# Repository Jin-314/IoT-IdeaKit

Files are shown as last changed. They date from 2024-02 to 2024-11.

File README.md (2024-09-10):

# Turtle Pico - Making electronics work easier and more widely

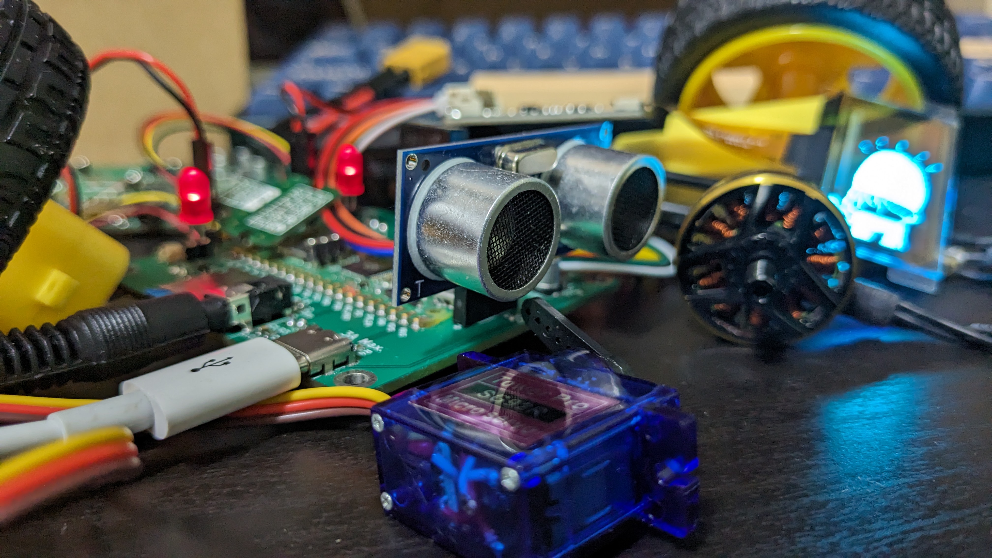
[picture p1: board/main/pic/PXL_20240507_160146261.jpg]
Turtle Pico


The Turtle Pico Board which looks like a turtle, uses connectors on the board for easy connection to components. The board is equipped with Raspberry Pi Pico W, and programming is easy with Micropython.

When you want to build something, just buy the components and plug them into this board! That's all there is to wiring. Then all you have to do is write the programming.

Don't know how to program? Don't worry. You can find some programming examples in the official repository.

## Specific & Environment build

Please see the specifications for a summary of each use.

The specifications are available in Japanese and English, so you can check them in the language of your choice.

[English](board/main/specific/specific_en.pdf)

[Japanese](board/main/specific/specific_jp.pdf)

## Case

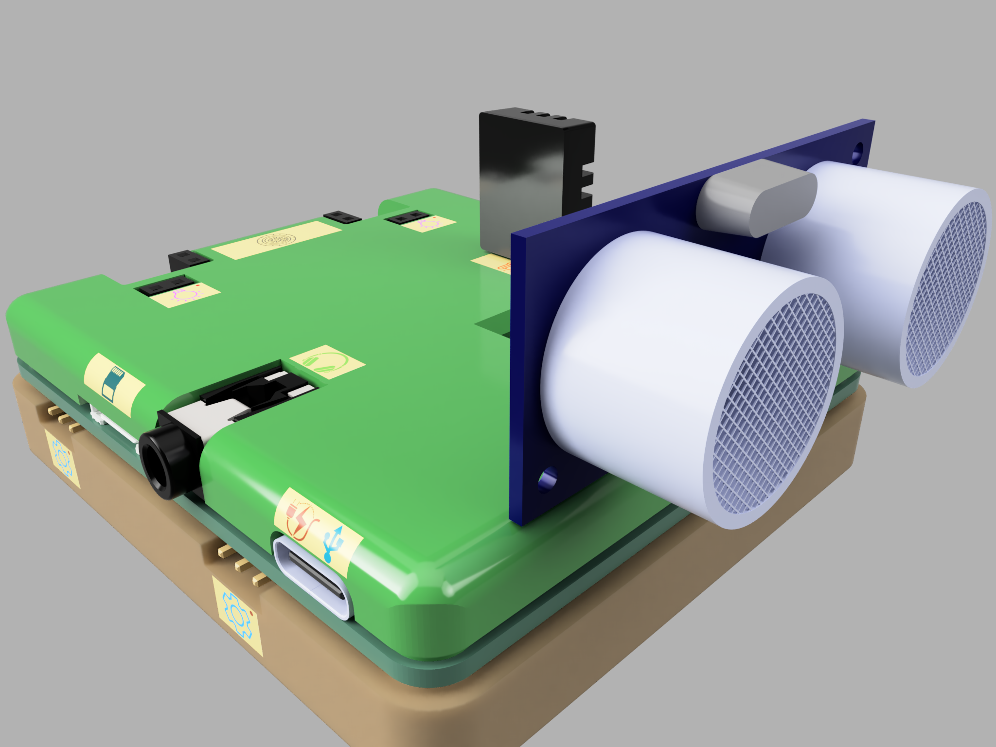
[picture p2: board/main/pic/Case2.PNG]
case


Turtle Pico Package is available in [**board/main/Case**](https://github.com/Jin-Neuron/Turtle-Pico/tree/master/board/main/Case).

## Purchase your board



Turtle Pico boards can currently only be purchased from [PCBWay's Shared Project Page](https://www.pcbway.com/project/shareproject/Turtle_Pico_Board_c183b11f.html). Once officially released, we plan to make it available for purchase at various online stores. 

## License

This repository includes multiple components with different licenses.

Please reffer to [LICENSE File](License.txt).

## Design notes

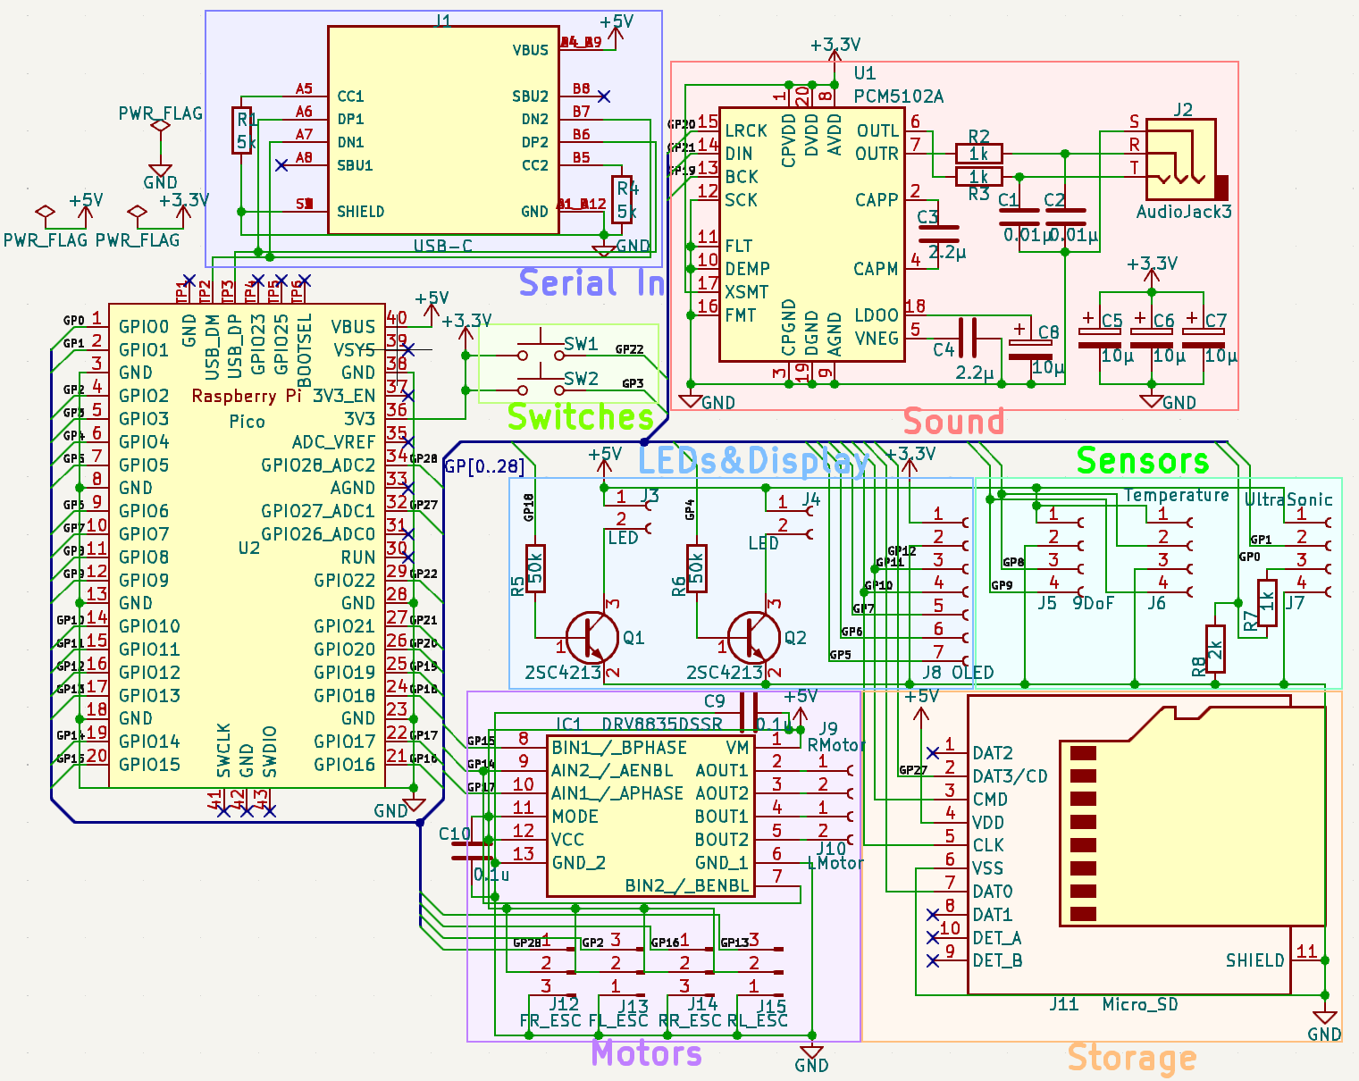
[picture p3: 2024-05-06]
board/main/pic/v.1/schematics.png

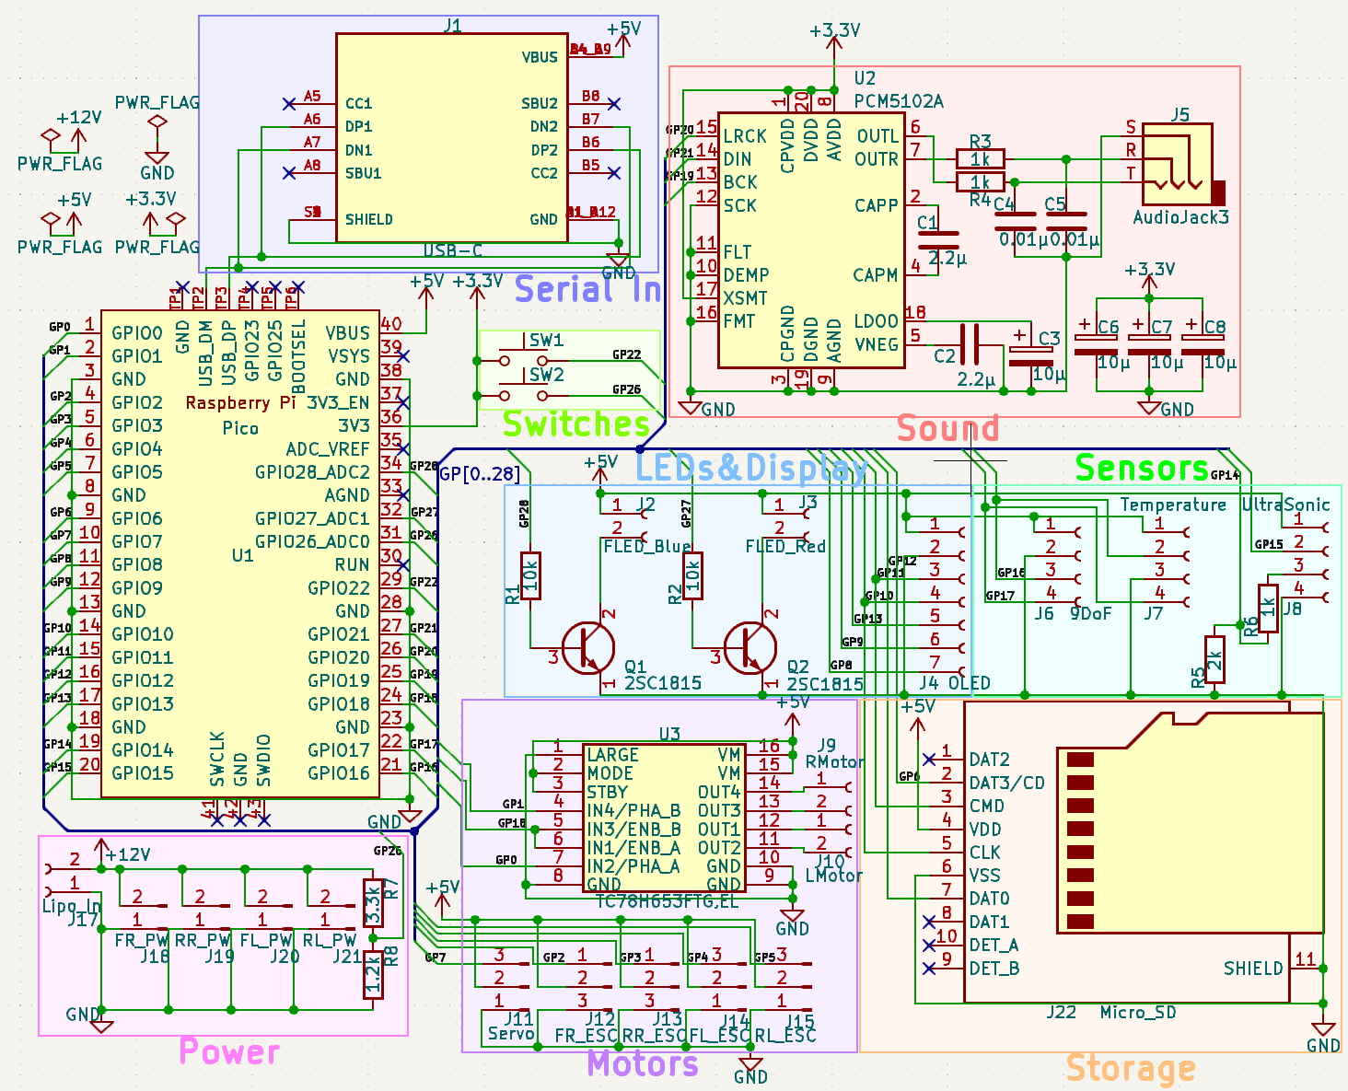
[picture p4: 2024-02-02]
board/trial/pic/Schematics.png

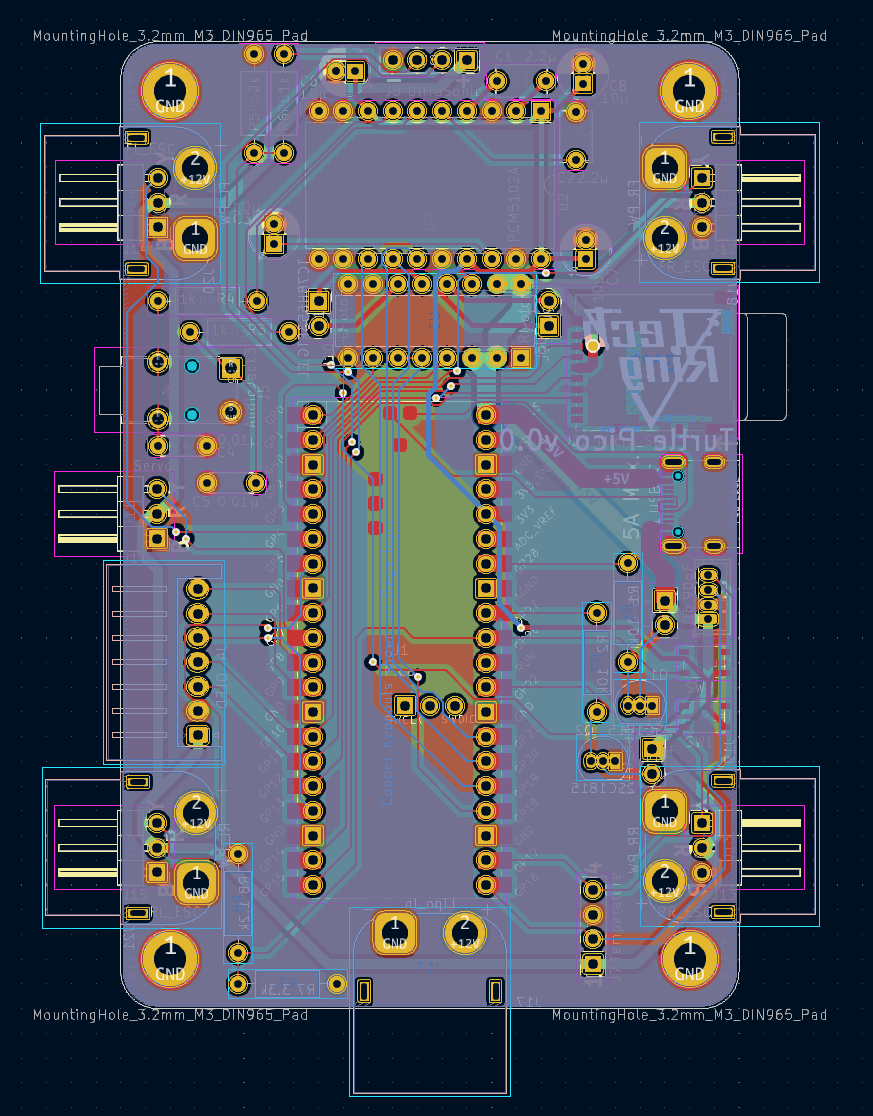
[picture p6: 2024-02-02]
board/trial/pic/PCB_4.png

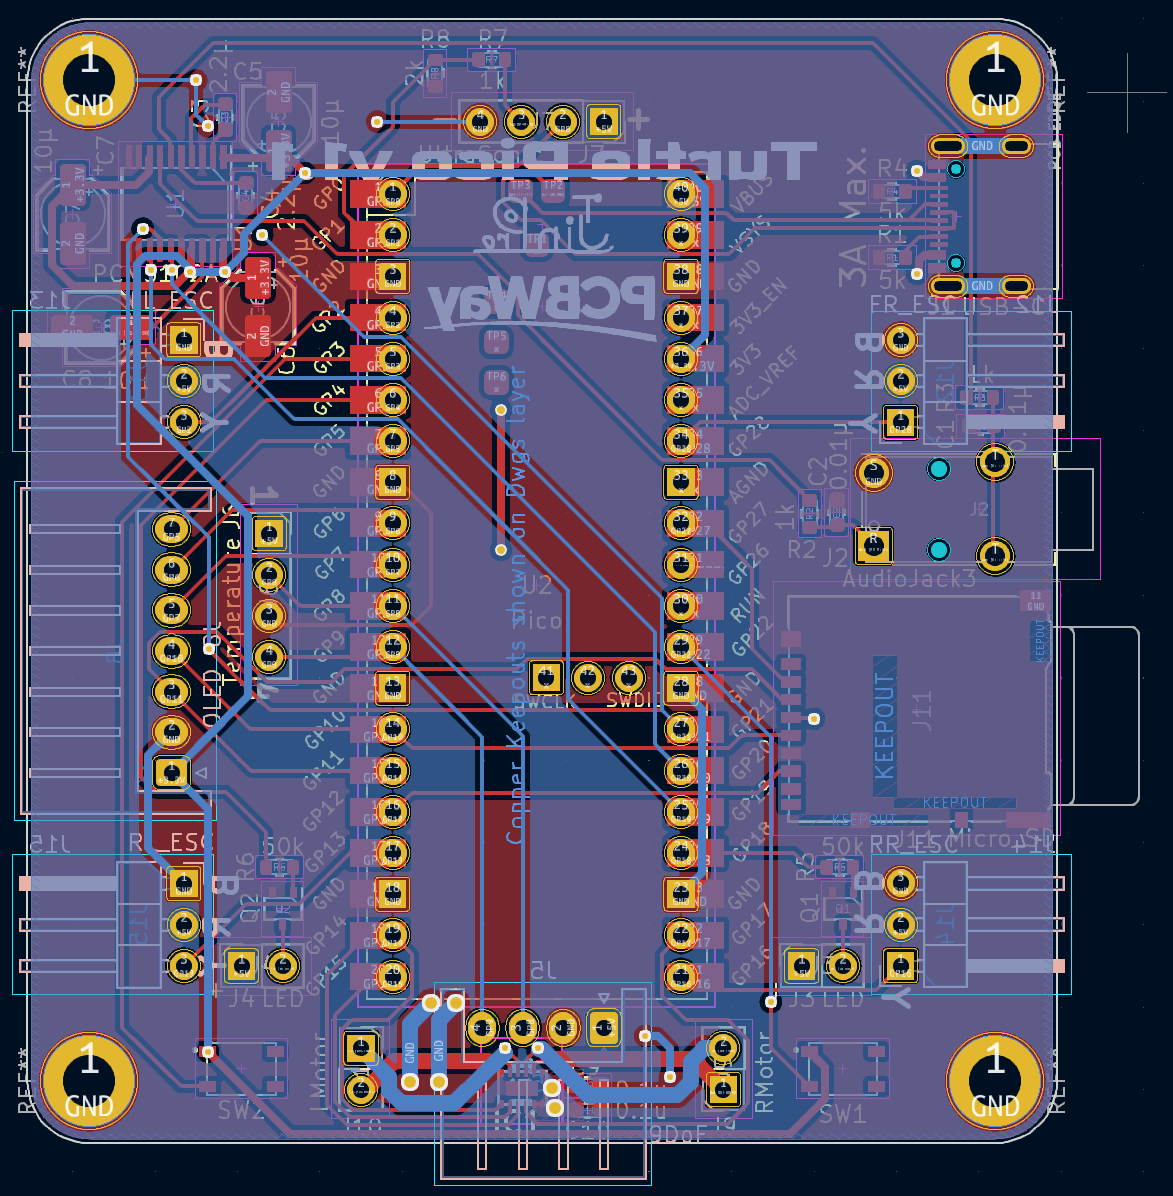
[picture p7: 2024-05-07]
board/main/pic/v.1/PCB_2.png

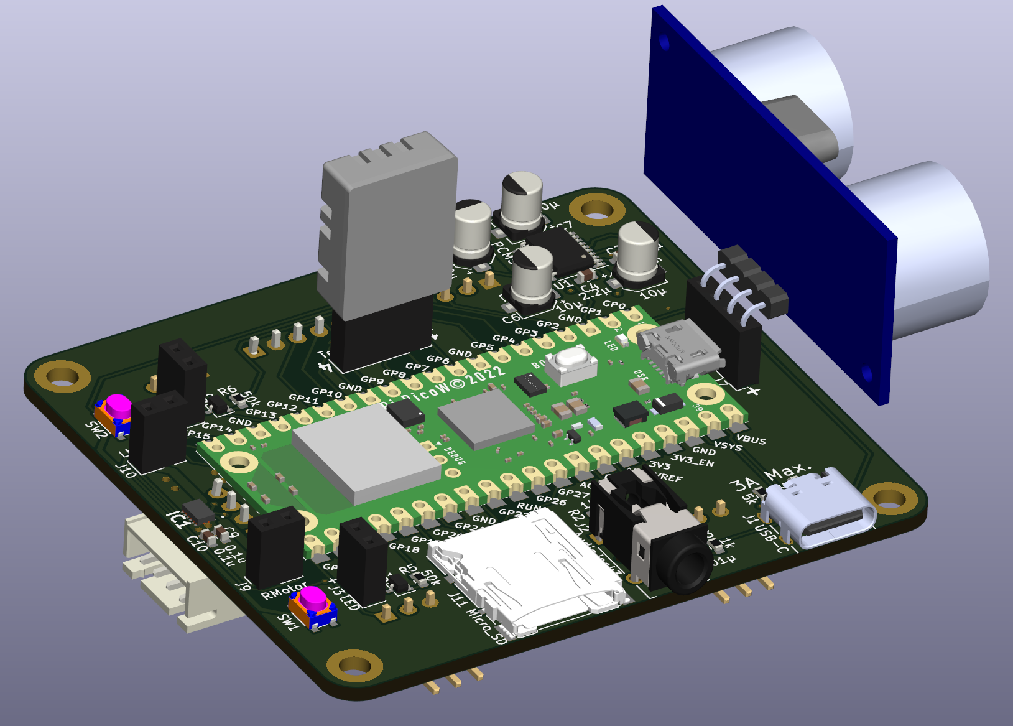
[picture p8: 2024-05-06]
board/main/pic/v.1/3D.png

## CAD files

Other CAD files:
board/main/Case/UpperCase.step
board/main/TurtlePico.step
board/trial/TurtlePico.step
board/main/Case/LowerCase.step

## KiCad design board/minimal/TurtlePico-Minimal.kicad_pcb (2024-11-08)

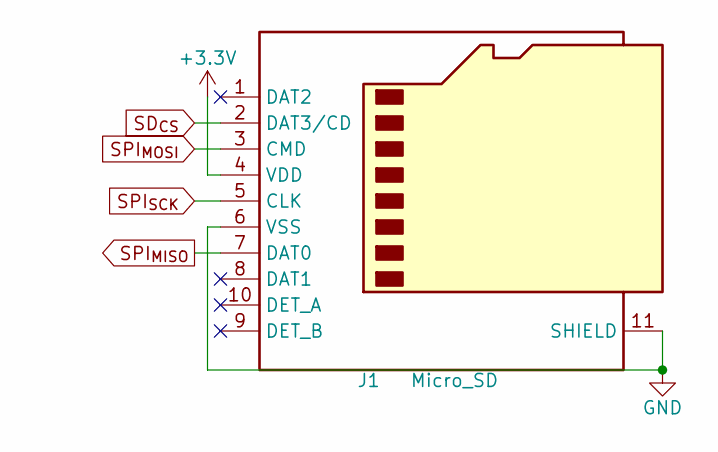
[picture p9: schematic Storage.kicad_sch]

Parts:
J1: Micro_SD; microSD_HC_Hirose_DM3D-SF; Manufacturer_Part_Number DM3AT-SF-PEJM5; Mouser Part Number 798-DM3AT-SF-PEJM5

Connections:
+3.3V: J1.4 (VDD); also elsewhere on the board
GND: J1.6 (VSS), J1.11 (SHIELD); also elsewhere on the board
SD_{CS}: J1.2 (DAT3/CD); also elsewhere on the board
SPI_{MISO}: J1.7 (DAT0); also elsewhere on the board
SPI_{MOSI}: J1.3 (CMD); also elsewhere on the board
SPI_{SCK}: J1.5 (CLK); also elsewhere on the board

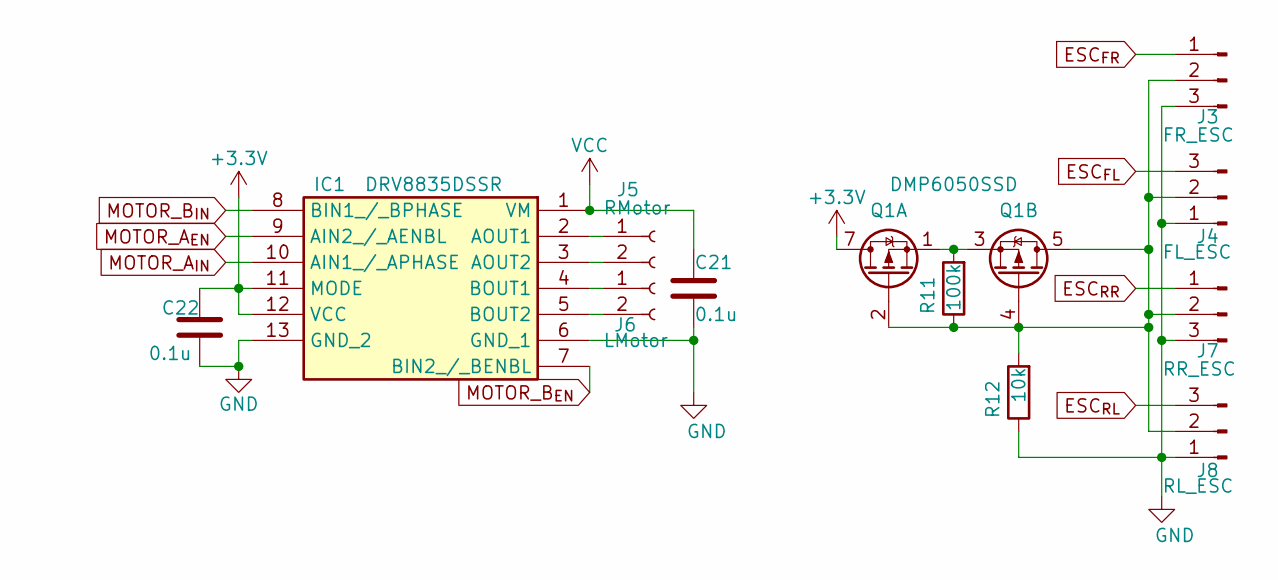
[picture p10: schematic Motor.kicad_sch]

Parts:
C21, C22: 0.1u; C_0201_0603Metric; Manufacturer_Part_Number GCM188R71C104KA37J; Mouser Part Number 81-GCM188R71C104KA7J
IC1: DRV8835DSSR; WSON-12-1EP_3x2mm_P0.5mm_EP1x2.65_ThermalVias; Mouser Part Number 595-DRV8835DSSR
J3: FR_ESC; PinHeader_1x03_P2.54mm_Horizontal
J4: FL_ESC; PinHeader_1x03_P2.54mm_Horizontal
J5: RMotor; PinSocket_1x02_P2.54mm_Vertical
J6: LMotor; PinSocket_1x02_P2.54mm_Vertical
J7: RR_ESC; PinHeader_1x03_P2.54mm_Horizontal
J8: RL_ESC; PinHeader_1x03_P2.54mm_Horizontal
Q1: DMP6050SSD; SOIC-8_3.9x4.9mm_P1.27mm
R11: 100k; R_0603_1608Metric; Manufacturer_Part_Number RN73H1JTTD5102F100; Mouser Part Number 660-RN73H1JT5102F100
R12: 10k; R_0603_1608Metric; Manufacturer_Part_Number RN73H1JTTD5102F100; Mouser Part Number 660-RN73H1JT5102F100

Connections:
+3.3V: C22.1, IC1.11 (MODE), IC1.12 (VCC), Q1.7 (D1), Q1.8 (D1); also elsewhere on the board
ESC_{FL}: J4.3; also elsewhere on the board
ESC_{FR}: J3.1; also elsewhere on the board
ESC_{RL}: J8.3; also elsewhere on the board
ESC_{RR}: J7.1; also elsewhere on the board
GND: C21.2, C22.2, IC1.6 (GND_1), IC1.13 (GND_2), J3.3, J4.1, J7.3, J8.1, R12.1; also elsewhere on the board
MOTOR_A_{EN}: IC1.9 (AIN2_/_AENBL); also elsewhere on the board
MOTOR_A_{IN}: IC1.10 (AIN1_/_APHASE); also elsewhere on the board
MOTOR_B_{EN}: IC1.7 (BIN2_/_BENBL); also elsewhere on the board
MOTOR_B_{IN}: IC1.8 (BIN1_/_BPHASE); also elsewhere on the board
unnamed: IC1.2 (AOUT1), J5.1
unnamed: IC1.3 (AOUT2), J5.2
unnamed: IC1.4 (BOUT1), J6.1
unnamed: IC1.5 (BOUT2), J6.2
unnamed: J3.2, J4.2, J7.2, J8.2, Q1.2 (G1), Q1.4 (G2), Q1.5 (D2), Q1.6 (D2), R11.1, R12.2
unnamed: Q1.1 (S1), Q1.3 (S2), R11.2
VCC: C21.1, IC1.1 (VM); also elsewhere on the board

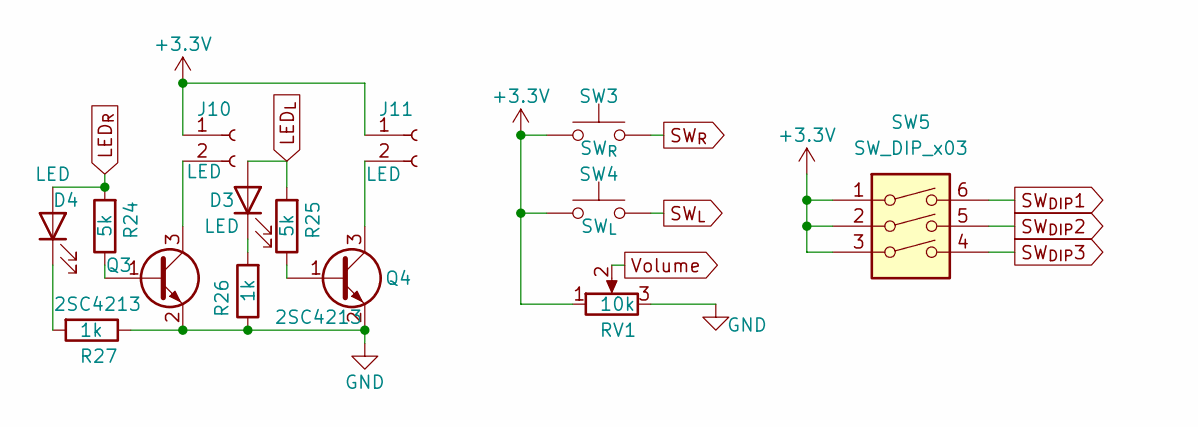
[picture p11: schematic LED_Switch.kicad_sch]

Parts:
D3, D4: LED; LED_0603_1608Metric
J10, J11: LED; PinSocket_1x02_P2.54mm_Vertical
Q3, Q4: 2SC4213; SOT-323_SC-70; Manufacturer_Part_Number 2SC4213-A(TE85L,F); Mouser Part Number 757-2SC4213-ATE85LF
R24, R25: 5k; R_0603_1608Metric; Manufacturer_Part_Number RN73H1JTTD5102F100; Mouser Part Number 660-RN73H1JT5102F100
R26, R27: 1k; R_0603_1608Metric; Manufacturer_Part_Number RN73H1JTTD5102F100; Mouser Part Number 660-RN73H1JT5102F100
RV1: 10k; Potentiometer_ACP_CA6-VSMD_Vertical
SW3: SW_{R}; SW_SKRPACE010
SW4: SW_{L}; SW_SKRPACE010
SW5: SW_DIP_x03; DS04254203BKSMT

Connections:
+3.3V: J10.1, J11.1, RV1.1, SW3.1, SW4.1, SW5.1, SW5.2, SW5.3; also elsewhere on the board
GND: Q3.2 (E), Q4.2 (E), R26.1, R27.1, RV1.3; also elsewhere on the board
LED_{L}: D3.2 (A), R25.2; also elsewhere on the board
LED_{R}: D4.2 (A), R24.2; also elsewhere on the board
unnamed: D3.1 (K), R26.2
unnamed: D4.1 (K), R27.2
unnamed: J10.2, Q3.3 (C)
unnamed: J11.2, Q4.3 (C)
unnamed: Q3.1 (B), R24.1
unnamed: Q4.1 (B), R25.1
SW_{DIP}1: SW5.6; also elsewhere on the board
SW_{DIP}2: SW5.5; also elsewhere on the board
SW_{DIP}3: SW5.4; also elsewhere on the board
SW_{L}: SW4.2; also elsewhere on the board
SW_{R}: SW3.2; also elsewhere on the board
Volume: RV1.2; also elsewhere on the board

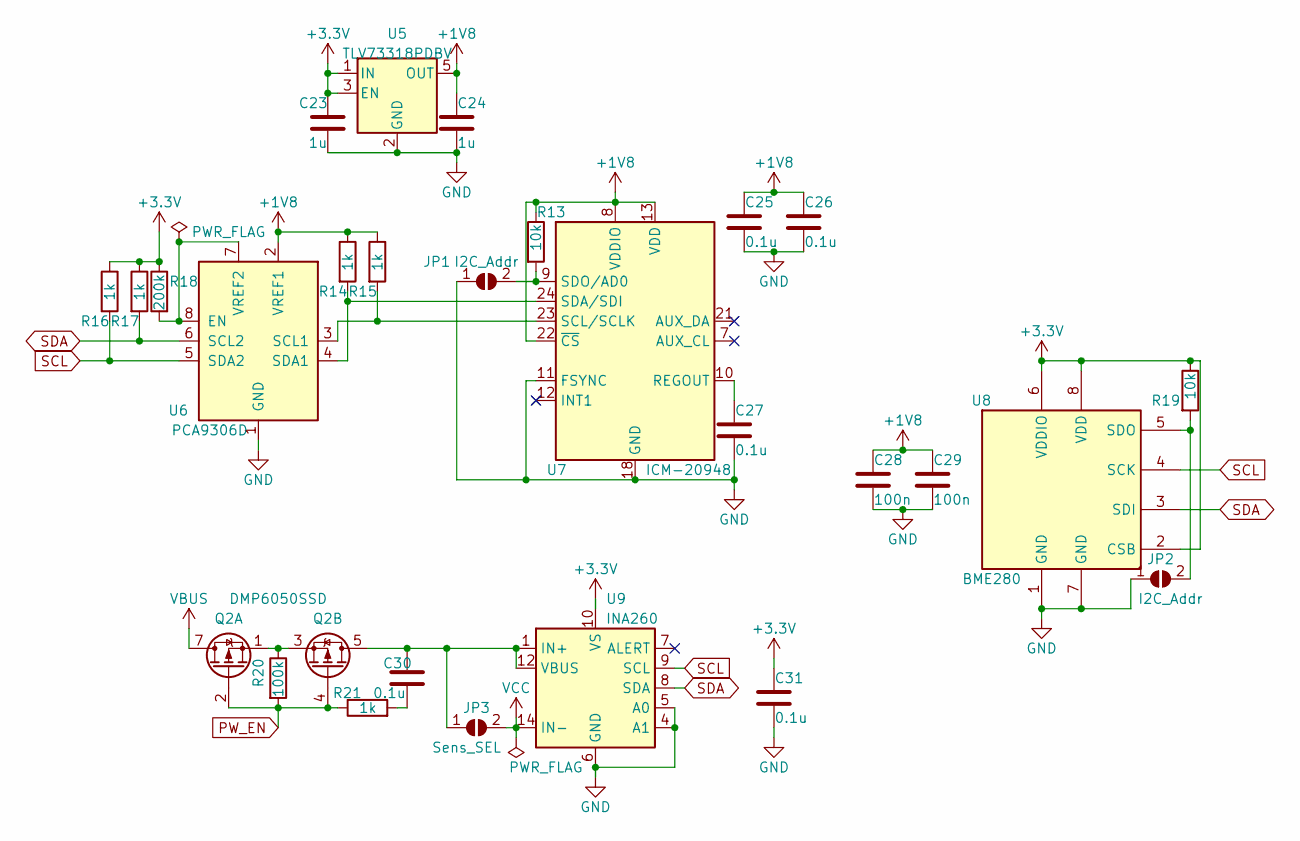
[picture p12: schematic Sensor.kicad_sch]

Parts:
C23, C24: 1u; C_0201_0603Metric
C25, C26, C27, C30, C31: 0.1u; C_0201_0603Metric
C28, C29: 100n; C_0201_0603Metric
JP1, JP2: I2C_Addr; SolderJumper-2_P1.3mm_Open_RoundedPad1.0x1.5mm
JP3: Sens_SEL; SolderJumper-2_P1.3mm_Open_RoundedPad1.0x1.5mm
Q2: DMP6050SSD; SOIC-8_3.9x4.9mm_P1.27mm
R13, R19: 10k; R_0603_1608Metric
R14, R15, R16, R17, R21: 1k; R_0603_1608Metric
R18: 200k; R_0603_1608Metric
R20: 100k; R_0603_1608Metric
U5: TLV73318PDBV; SOT-23-5
U6: PCA9306D; X2SON-8_1.4x1mm_P0.35mm
U7: ICM-20948; InvenSense_QFN-24_3x3mm_P0.4mm
U8: BME280; Bosch_LGA-8_2.5x2.5mm_P0.65mm_ClockwisePinNumbering
U9: INA260; TSSOP-16_4.4x5mm_P0.65mm

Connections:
+1V8: C24.1, C25.1, C26.1, C28.1, C29.1, R13.1, R14.1, R15.1, U5.5 (OUT), U6.2 (VREF1), U7.8 (VDDIO), U7.13 (VDD), U7.22 (~CS)
+3.3V: C23.1, C31.1, R16.1, R17.1, R18.1, R19.1, U5.1 (IN), U5.3 (EN), U8.2 (CSB), U8.6 (VDDIO), U8.8 (VDD), U9.10 (VS); also elsewhere on the board
GND: C23.2, C24.2, C25.2, C26.2, C27.2, C28.2, C29.2, C31.2, JP1.1 (A), JP2.1 (A), U5.2 (GND), U6.1 (GND), U7.11 (FSYNC), U7.18 (GND), U7.20 (GND), U8.1 (GND), U8.7 (GND), U9.4 (A1), U9.5 (A0), U9.6 (GND), U9.11 (GND); also elsewhere on the board
unnamed: C30.2, R21.2
unnamed: JP1.2 (B), R13.2, U7.9 (SDO/AD0)
unnamed: JP2.2 (B), R19.2, U8.5 (SDO)
unnamed: C30.1, JP3.1 (A), Q2.5 (D2), Q2.6 (D2), U9.1 (IN+), U9.2 (IN+), U9.3 (IN+), U9.12 (VBUS)
unnamed: Q2.1 (S1), Q2.3 (S2), R20.1
unnamed: R18.2, U6.7 (VREF2), U6.8 (EN)
unnamed: R15.2, U6.3 (SCL1), U7.23 (SCL/SCLK)
unnamed: R14.2, U6.4 (SDA1), U7.24 (SDA/SDI)
unnamed: C27.1, U7.10 (REGOUT)
PW_EN: Q2.2 (G1), Q2.4 (G2), R20.2, R21.1; also elsewhere on the board
SCL: R16.2, U6.5 (SDA2), U8.4 (SCK), U9.9 (SCL); also elsewhere on the board
SDA: R17.2, U6.6 (SCL2), U8.3 (SDI), U9.8 (SDA); also elsewhere on the board
VBUS: Q2.7 (D1), Q2.8 (D1); also elsewhere on the board
VCC: JP3.2 (B), U9.14 (IN-), U9.15 (IN-), U9.16 (IN-); also elsewhere on the board

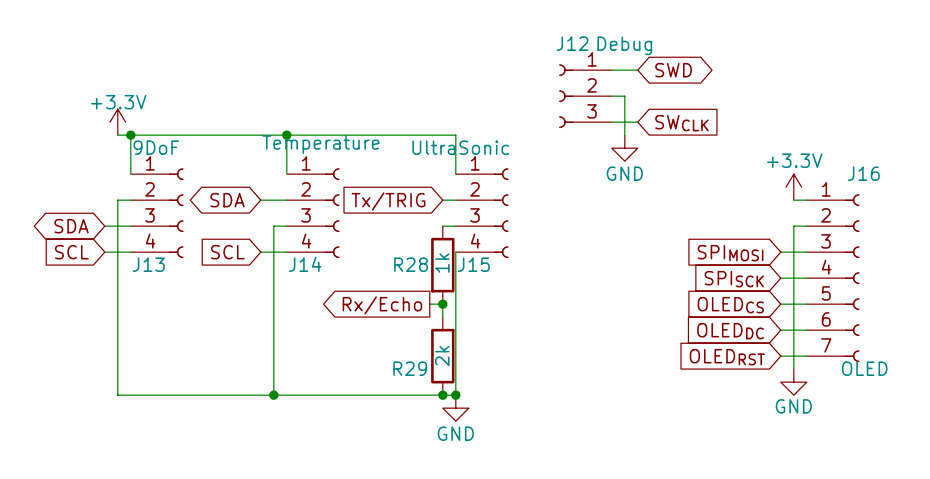
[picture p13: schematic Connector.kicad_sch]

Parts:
J12: Debug; JST_PH_B3B-PH-SM4-TB_1x03-1MP_P2.00mm_Vertical
J13: 9DoF; JST_XH_S4B-XH-A_1x04_P2.50mm_Horizontal
J14: Temperature; PinSocket_1x04_P2.54mm_Vertical
J15: UltraSonic; PinSocket_1x04_P2.54mm_Vertical
J16: OLED; JST_XH_S7B-XH-A_1x07_P2.50mm_Horizontal
R28: 1k; R_0603_1608Metric; Manufacturer_Part_Number RN73H1JTTD1001F100; Mouser Part Number 660-RN73H1JT1001F100
R29: 2k; R_0603_1608Metric; Manufacturer_Part_Number RN73H1JTTD2001F25; Mouser Part Number 660-RN73H1JTD2001F25

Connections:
+3.3V: J13.1, J14.1, J15.1, J16.1; also elsewhere on the board
GND: J12.2, J13.2, J14.3, J15.4, J16.2, R29.1; also elsewhere on the board
unnamed: J15.3, R28.1
OLED_{CS}: J16.5; also elsewhere on the board
OLED_{DC}: J16.6; also elsewhere on the board
OLED_{RST}: J16.7; also elsewhere on the board
Rx/Echo: R28.2, R29.2; also elsewhere on the board
SCL: J13.4, J14.4; also elsewhere on the board
SDA: J13.3, J14.2; also elsewhere on the board
SPI_{MOSI}: J16.3; also elsewhere on the board
SPI_{SCK}: J16.4; also elsewhere on the board
SWD: J12.1; also elsewhere on the board
SW_{CLK}: J12.3; also elsewhere on the board
Tx/TRIG: J15.2; also elsewhere on the board

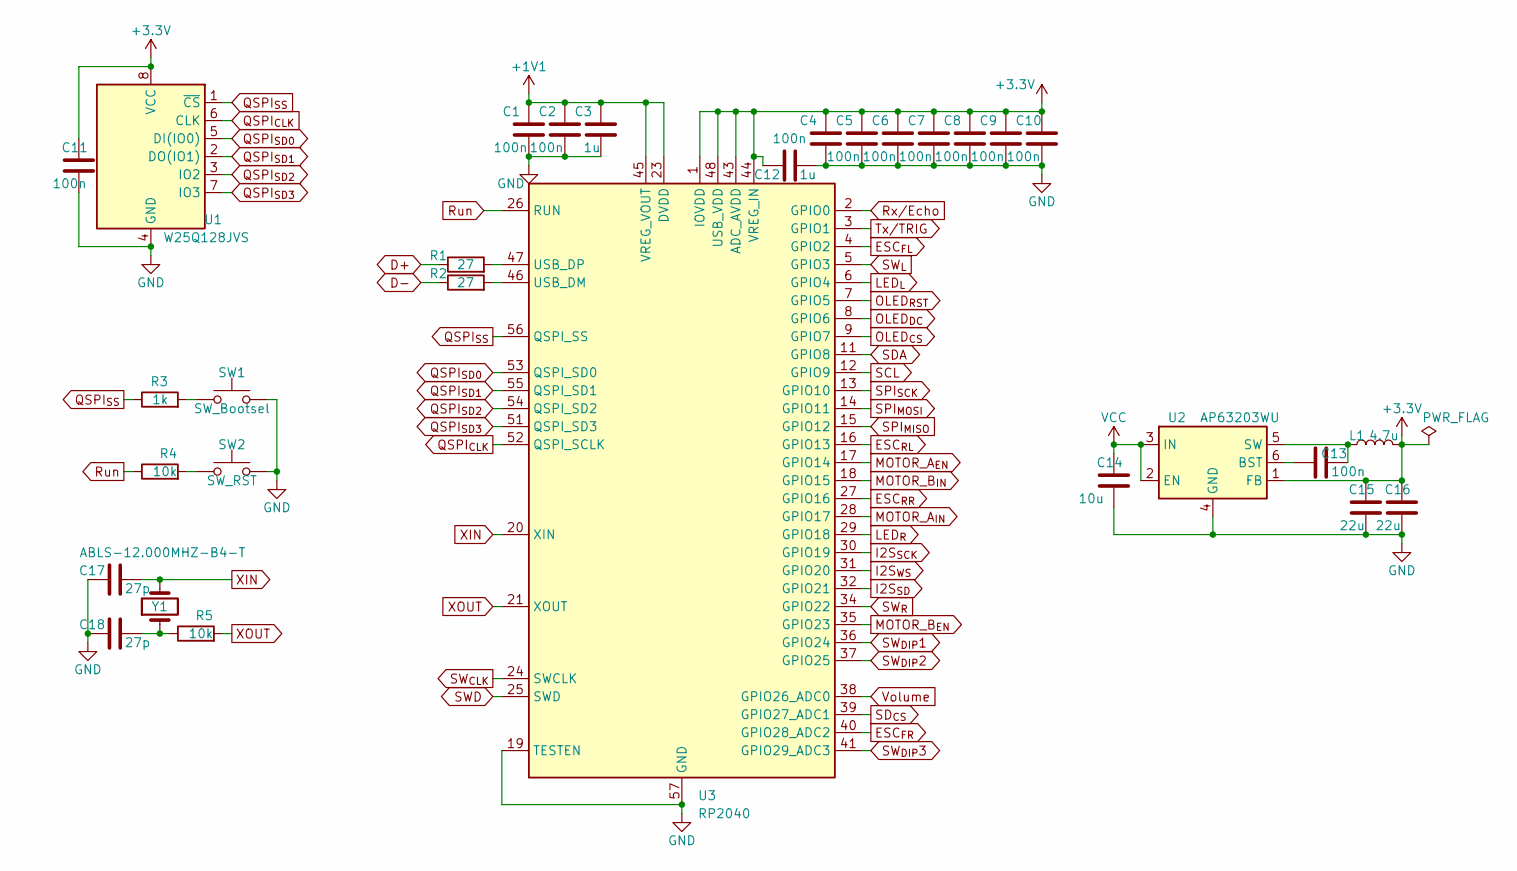
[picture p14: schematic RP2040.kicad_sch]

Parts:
C1, C2, C4, C5, C6, C7, C8, C9, C10, C11, C13: 100n; C_0201_0603Metric
C3, C12: 1u; C_0201_0603Metric
C14: 10u; C_1206_3216Metric
C15, C16: 22u; C_0402_1005Metric
C17, C18: 27p; C_0201_0603Metric
L1: 4.7u; C_0603_1608Metric
R1, R2: 27; R_0603_1608Metric
R3: 1k; R_0603_1608Metric
R4, R5: 10k; R_0603_1608Metric
SW1: SW_Bootsel; SW_SKRPACE010
SW2: SW_RST; SW_SKRPACE010
U1: W25Q128JVS; SOIC-8_5.23x5.23mm_P1.27mm
U2: AP63203WU; TSOT-23-6
U3: RP2040; QFN-56-1EP_7x7mm_P0.4mm_EP3.2x3.2mm
Y1: ABLS-12.000MHZ-B4-T; ABLS

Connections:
+1V1: C1.1, C2.1, C3.1, U3.23 (DVDD), U3.45 (VREG_VOUT), U3.50 (DVDD)
+3.3V: C4.1, C5.1, C6.1, C7.1, C8.1, C9.1, C10.1, C11.1, C12.1, C15.1, C16.1, L1.2, U1.8 (VCC), U2.1 (FB), U3.1 (IOVDD), U3.10 (IOVDD), U3.22 (IOVDD), U3.33 (IOVDD), U3.42 (IOVDD), U3.43 (ADC_AVDD), U3.44 (VREG_IN), U3.48 (USB_VDD), U3.49 (IOVDD); also elsewhere on the board
D+: R1.1; also elsewhere on the board
D-: R2.1; also elsewhere on the board
ESC_{FL}: U3.4 (GPIO2); also elsewhere on the board
ESC_{FR}: U3.40 (GPIO28_ADC2); also elsewhere on the board
ESC_{RL}: U3.16 (GPIO13); also elsewhere on the board
ESC_{RR}: U3.27 (GPIO16); also elsewhere on the board
GND: C1.2, C2.2, C3.2, C4.2, C5.2, C6.2, C7.2, C8.2, C9.2, C10.2, C11.2, C12.2, C14.2, C15.2, C16.2, C17.1, C18.1, SW1.2, SW2.2, U1.4 (GND), U2.4 (GND), U3.19 (TESTEN), U3.57 (GND); also elsewhere on the board
I2S_{SCK}: U3.30 (GPIO19); also elsewhere on the board
I2S_{SD}: U3.32 (GPIO21); also elsewhere on the board
I2S_{WS}: U3.31 (GPIO20); also elsewhere on the board
LED_{L}: U3.6 (GPIO4); also elsewhere on the board
LED_{R}: U3.29 (GPIO18); also elsewhere on the board
MOTOR_A_{EN}: U3.17 (GPIO14); also elsewhere on the board
MOTOR_A_{IN}: U3.28 (GPIO17); also elsewhere on the board
MOTOR_B_{EN}: U3.35 (GPIO23); also elsewhere on the board
MOTOR_B_{IN}: U3.18 (GPIO15); also elsewhere on the board
unnamed: C18.2, R5.1, Y1.1
unnamed: R3.2, SW1.1
unnamed: R4.2, SW2.1
unnamed: C13.1, U2.6 (BST)
unnamed: C13.2, L1.1, U2.5 (SW)
unnamed: R2.2, U3.46 (USB_DM)
unnamed: R1.2, U3.47 (USB_DP)
OLED_{CS}: U3.9 (GPIO7); also elsewhere on the board
OLED_{DC}: U3.8 (GPIO6); also elsewhere on the board
OLED_{RST}: U3.7 (GPIO5); also elsewhere on the board
QSPI_{CLK}: U1.6 (CLK), U3.52 (QSPI_SCLK)
QSPI_{SD0}: U1.5 (DI(IO0)), U3.53 (QSPI_SD0)
QSPI_{SD1}: U1.2 (DO(IO1)), U3.55 (QSPI_SD1)
QSPI_{SD2}: U1.3 (IO2), U3.54 (QSPI_SD2)
QSPI_{SD3}: U1.7 (IO3), U3.51 (QSPI_SD3)
QSPI_{SS}: R3.1, U1.1 (~CS), U3.56 (QSPI_SS)
Run: R4.1, U3.26 (RUN)
Rx/Echo: U3.2 (GPIO0); also elsewhere on the board
SCL: U3.12 (GPIO9); also elsewhere on the board
SDA: U3.11 (GPIO8); also elsewhere on the board
SD_{CS}: U3.39 (GPIO27_ADC1); also elsewhere on the board
SPI_{MISO}: U3.15 (GPIO12); also elsewhere on the board
SPI_{MOSI}: U3.14 (GPIO11); also elsewhere on the board
SPI_{SCK}: U3.13 (GPIO10); also elsewhere on the board
SWD: U3.25 (SWD); also elsewhere on the board
SW_{CLK}: U3.24 (SWCLK); also elsewhere on the board
SW_{DIP}1: U3.36 (GPIO24); also elsewhere on the board
SW_{DIP}2: U3.37 (GPIO25); also elsewhere on the board
SW_{DIP}3: U3.41 (GPIO29_ADC3); also elsewhere on the board
SW_{L}: U3.5 (GPIO3); also elsewhere on the board
SW_{R}: U3.34 (GPIO22); also elsewhere on the board
Tx/TRIG: U3.3 (GPIO1); also elsewhere on the board
VCC: C14.1, U2.2 (EN), U2.3 (IN); also elsewhere on the board
Volume: U3.38 (GPIO26_ADC0); also elsewhere on the board
XIN: C17.2, U3.20 (XIN), Y1.2
XOUT: R5.2, U3.21 (XOUT)

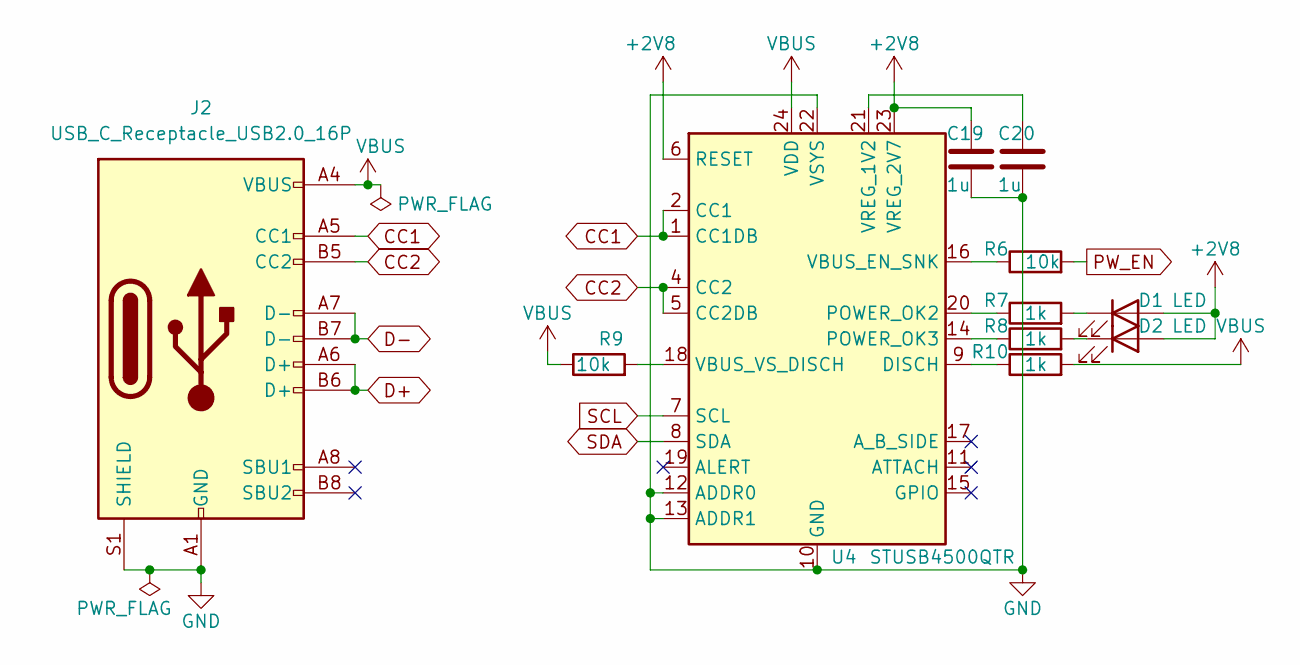
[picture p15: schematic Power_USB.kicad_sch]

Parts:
C19, C20: 1u; C_0201_0603Metric
D1, D2: LED; LED_0603_1608Metric
J2: USB_C_Receptacle_USB2.0_16P; USB_C_Receptacle_GCT_USB4085
R6, R9: 10k; R_0603_1608Metric
R7, R8, R10: 1k; R_0603_1608Metric
U4: STUSB4500QTR; QFN-24-1EP_4x4mm_P0.5mm_EP2.7x2.7mm

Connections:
+2V8: C19.1, D1.2 (A), D2.2 (A), U4.6 (RESET), U4.23 (VREG_2V7)
CC1: J2.A5 (CC1), U4.1 (CC1DB), U4.2 (CC1)
CC2: J2.B5 (CC2), U4.4 (CC2), U4.5 (CC2DB)
D+: J2.A6 (D+), J2.B6 (D+); also elsewhere on the board
D-: J2.A7 (D-), J2.B7 (D-); also elsewhere on the board
GND: C19.2, C20.2, J2.A1 (GND), J2.A12 (GND), J2.B1 (GND), J2.B12 (GND), J2.S1 (SHIELD), U4.10 (GND), U4.12 (ADDR0), U4.13 (ADDR1), U4.22 (VSYS), U4.25 (GND); also elsewhere on the board
unnamed: D1.1 (K), R7.2
unnamed: D2.1 (K), R8.2
unnamed: R10.1, U4.9 (DISCH)
unnamed: R7.1, U4.20 (POWER_OK2)
unnamed: R8.1, U4.14 (POWER_OK3)
unnamed: R6.1, U4.16 (VBUS_EN_SNK)
unnamed: R9.2, U4.18 (VBUS_VS_DISCH)
unnamed: C20.1, U4.21 (VREG_1V2)
PW_EN: R6.2; also elsewhere on the board
SCL: U4.7 (SCL); also elsewhere on the board
SDA: U4.8 (SDA); also elsewhere on the board
VBUS: J2.A4 (VBUS), J2.A9 (VBUS), J2.B4 (VBUS), J2.B9 (VBUS), R9.1, R10.2, U4.24 (VDD); also elsewhere on the board

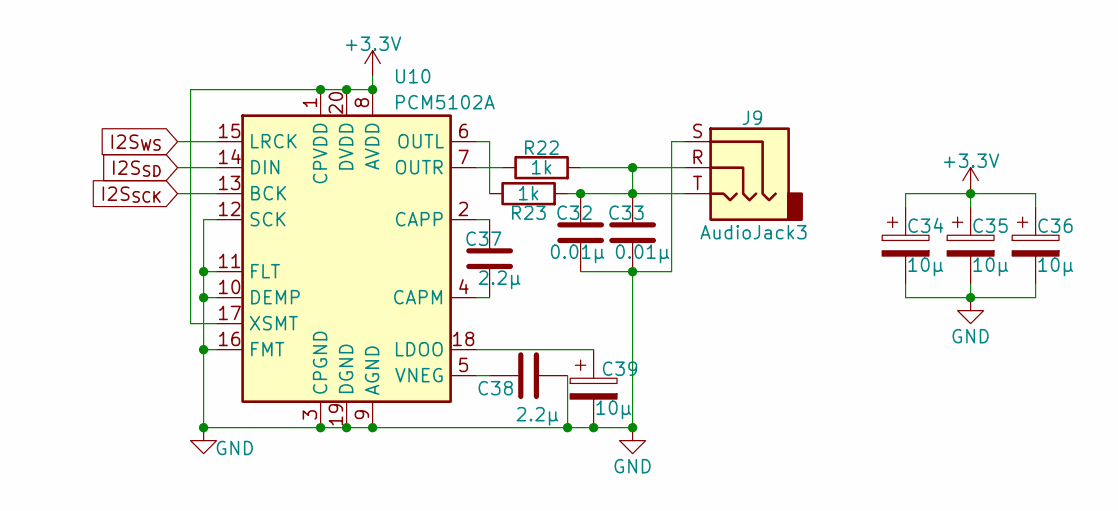
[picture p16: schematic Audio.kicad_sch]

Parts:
C32, C33: 0.01µ; C_0201_0603Metric; Manufacturer_Part_Number GCM188R71H103KA37J; Mouser Part Number 81-GCM188R71H103KA7J
C34, C35, C36, C39: 10µ; CP_Elec_4x5.4; Manufacturer_Part_Number EEE-FN1A100R; Mouser Part Number 667-EEE-FN1A100R
C37, C38: 2.2µ; C_0201_0603Metric; Manufacturer_Part_Number GRM188R61H225KE11D; Mouser Part Number 81-GRM188R61H225KE1D
J9: AudioJack3; STX3000; Manufacturer_Part_Number STX-3000; Mouser Part Number 806-STX-3000
R22, R23: 1k; R_0603_1608Metric; Manufacturer_Part_Number RN73H1JTTD1001F100; Mouser Part Number 660-RN73H1JT1001F100
U10: PCM5102A; TSSOP-20_4.4x6.5mm_P0.65mm; Manufacturer_Part_Number PCM5102APWR; Mouser Part Number 595-PCM5102APWR

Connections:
+3.3V: C34.1, C35.1, C36.1, U10.1 (CPVDD), U10.8 (AVDD), U10.17 (XSMT), U10.20 (DVDD); also elsewhere on the board
GND: C32.2, C33.2, C34.2, C35.2, C36.2, C38.2, C39.2, J9.S, U10.3 (CPGND), U10.9 (AGND), U10.10 (DEMP), U10.11 (FLT), U10.12 (SCK), U10.16 (FMT), U10.19 (DGND); also elsewhere on the board
I2S_{SCK}: U10.13 (BCK); also elsewhere on the board
I2S_{SD}: U10.14 (DIN); also elsewhere on the board
I2S_{WS}: U10.15 (LRCK); also elsewhere on the board
unnamed: C32.1, C33.1, J9.R, J9.T, R22.2, R23.2
unnamed: C37.2, U10.4 (CAPM)
unnamed: C37.1, U10.2 (CAPP)
unnamed: C39.1, U10.18 (LDOO)
unnamed: R23.1, U10.6 (OUTL)
unnamed: R22.1, U10.7 (OUTR)
unnamed: C38.1, U10.5 (VNEG)

Board: 2 copper layers, 114 parts (8 on the bottom side), 97 nets, no tracks yet.

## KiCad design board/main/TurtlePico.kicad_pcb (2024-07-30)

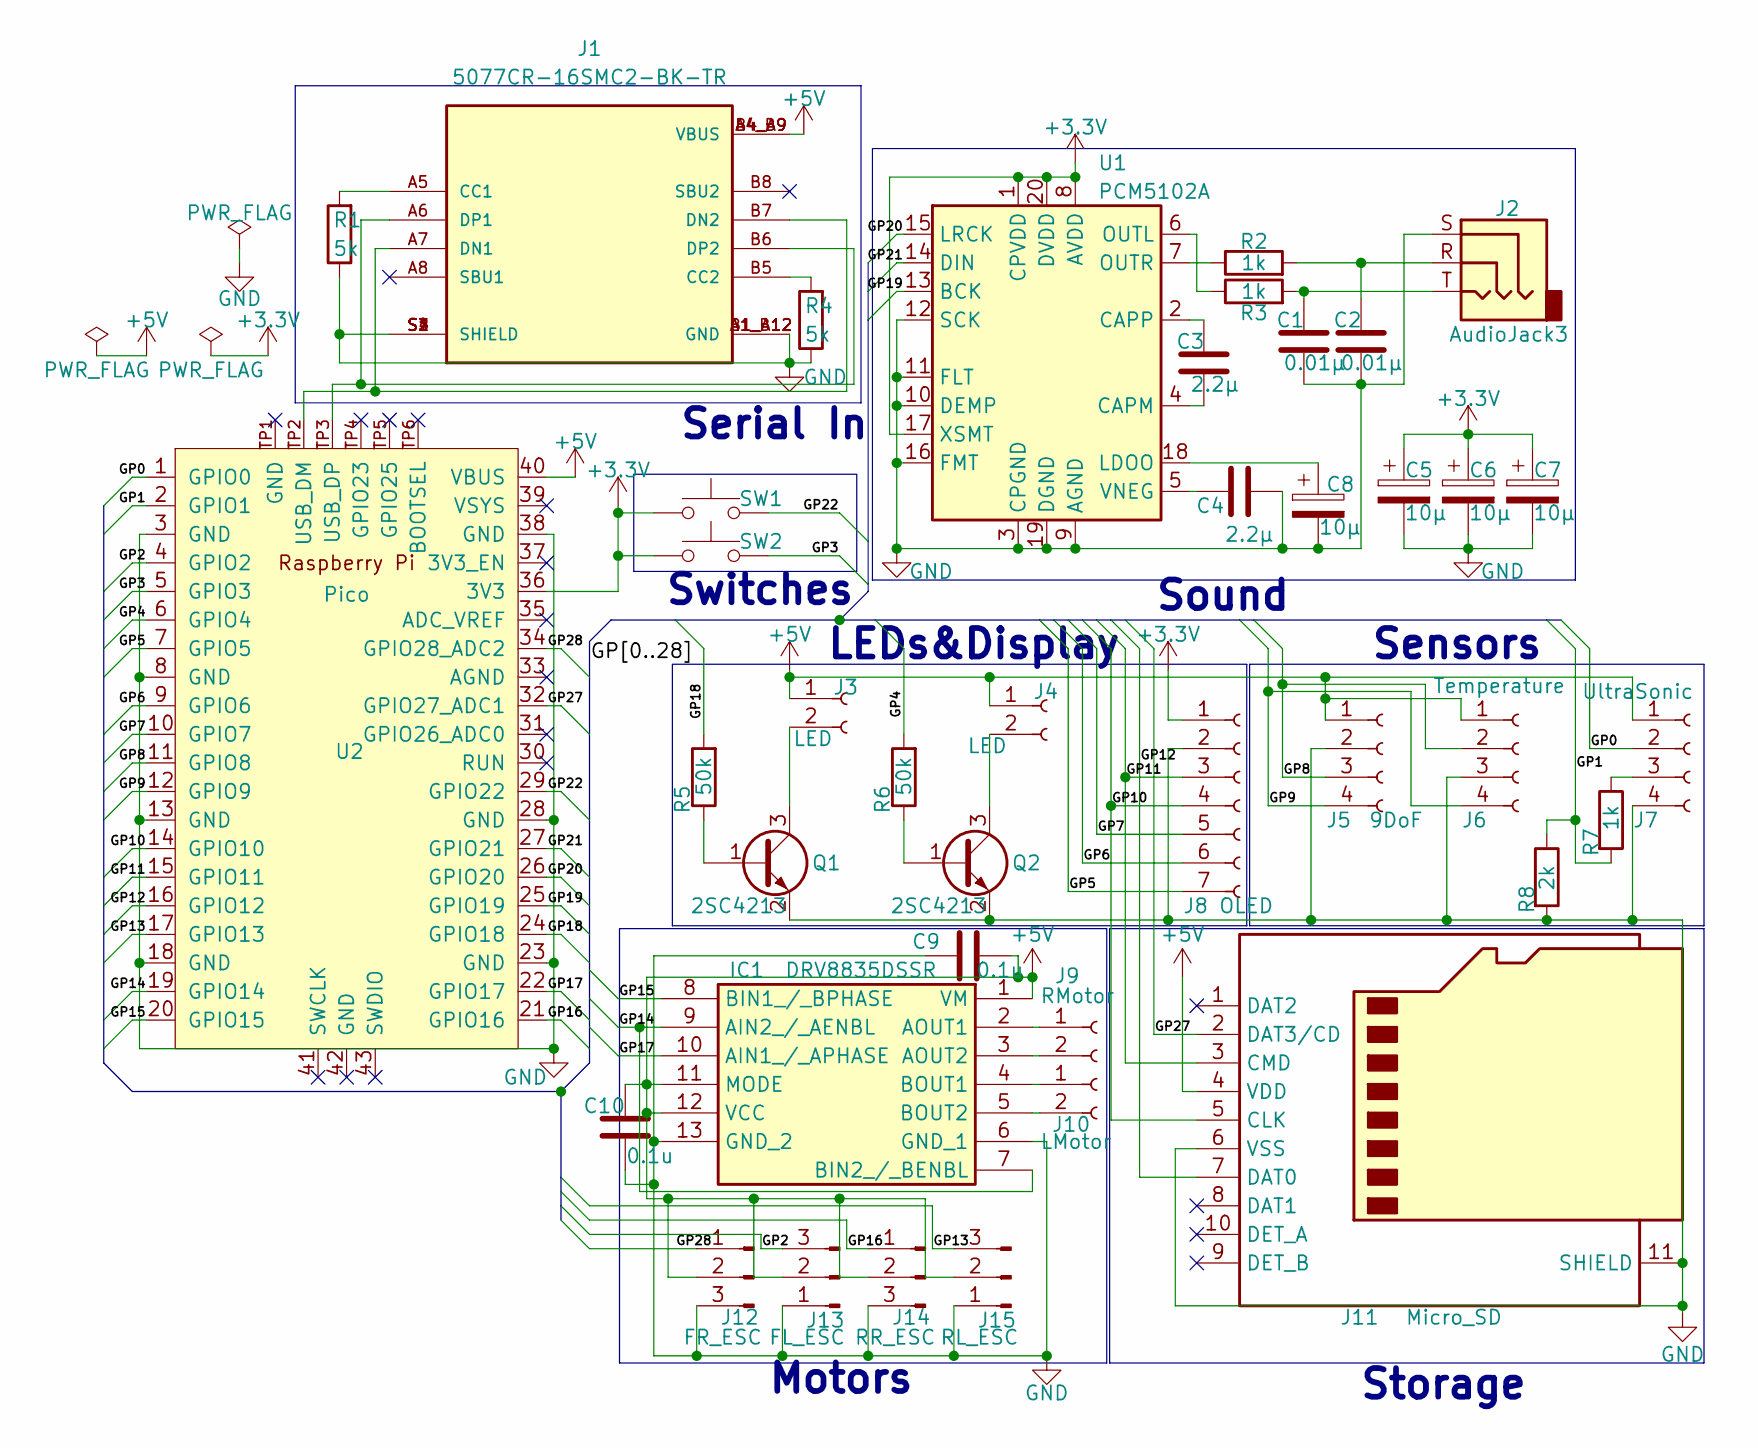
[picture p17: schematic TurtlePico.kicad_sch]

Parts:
C1, C2: 0.01µ; C_0603_1608Metric; Manufacturer_Part_Number GCM188R71H103KA37J; Mouser Part Number 81-GCM188R71H103KA7J
C3, C4: 2.2µ; C_0603_1608Metric; Manufacturer_Part_Number GRM188R61H225KE11D; Mouser Part Number 81-GRM188R61H225KE1D
C5, C6, C7, C8: 10µ; CP_Elec_4x5.4; Manufacturer_Part_Number EEE-FN1A100R; Mouser Part Number 667-EEE-FN1A100R
C9, C10: 0.1u; C_0603_1608Metric; Manufacturer_Part_Number GCM188R71C104KA37J; Mouser Part Number 81-GCM188R71C104KA7J
IC1: DRV8835DSSR; Mouser Part Number 595-DRV8835DSSR
J1: 5077CR-16SMC2-BK-TR; NELTRON_5077CR-16SMC2-BK-TR; Manufacturer_Part_Number USB4105-GF-A-060; Mouser Part Number 640-USB4105-GF-A-060
J2: AudioJack3; STX3000; Manufacturer_Part_Number STX-3000; Mouser Part Number 806-STX-3000
J3, J4: LED; PinSocket_1x02_P2.54mm_Vertical
J5: 9DoF; JST_XH_S4B-XH-A_1x04_P2.50mm_Horizontal
J6: Temperature; PinSocket_1x04_P2.54mm_Vertical
J7: UltraSonic; PinSocket_1x04_P2.54mm_Vertical
J8: OLED; JST_XH_S7B-XH-A_1x07_P2.50mm_Horizontal
J9: RMotor; PinSocket_1x02_P2.54mm_Vertical
J10: LMotor; PinSocket_1x02_P2.54mm_Vertical
J11: Micro_SD; microSD_HC_Hirose_DM3AT-SF-PEJM5; Manufacturer_Part_Number DM3AT-SF-PEJM5; Mouser Part Number 798-DM3AT-SF-PEJM5
J12: FR_ESC; PinHeader_1x03_P2.54mm_Horizontal
J13: FL_ESC; PinHeader_1x03_P2.54mm_Horizontal
J14: RR_ESC; PinHeader_1x03_P2.54mm_Horizontal
J15: RL_ESC; PinHeader_1x03_P2.54mm_Horizontal
Q1, Q2: 2SC4213; SOT-323_SC-70; Manufacturer_Part_Number 2SC4213-A(TE85L,F); Mouser Part Number 757-2SC4213-ATE85LF
R1, R4: 5k; R_0603_1608Metric; Manufacturer_Part_Number RN73H1JTTD5101D100; Mouser Part Number 660-RN73H1JT5101D100
R2, R3, R7: 1k; R_0603_1608Metric; Manufacturer_Part_Number RN73H1JTTD1001F100; Mouser Part Number 660-RN73H1JT1001F100
R5, R6: 50k; R_0603_1608Metric; Manufacturer_Part_Number RN73H1JTTD5102F100; Mouser Part Number 660-RN73H1JT5102F100
R8: 2k; R_0603_1608Metric; Manufacturer_Part_Number RN73H1JTTD2001F25; Mouser Part Number 660-RN73H1JTD2001F25
SW1, SW2: SW_Push; SW_SKRPACE010; Manufacturer_Part_Number SKRPACE010; Mouser Part Number 688-SKRPACE010
U1: PCM5102A; TSSOP-20_4.4x6.5mm_P0.65mm; Manufacturer_Part_Number PCM5102APWR; Mouser Part Number 595-PCM5102APWR
U2: Pico; RPi_Pico_SMD_TH; Manufacturer_Part_Number SC0918; Mouser Part Number 358-SC0918

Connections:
+3.3V: C5.1, C6.1, C7.1, J8.1, SW1.1, SW2.1, U1.1 (CPVDD), U1.8 (AVDD), U1.17 (XSMT), U1.20 (DVDD), U2.36 (3V3)
+5V: C9.1, C10.1, IC1.1 (VM), IC1.11 (MODE), IC1.12 (VCC), J1.A4_B9 (VBUS), J1.B4_A9 (VBUS), J3.1, J4.1, J5.1, J6.1, J7.1, J11.4 (VDD), J12.2, J13.2, J14.2, J15.2, U2.40 (VBUS)
/GP0: J7.2, U2.1 (GPIO0)
/GP1: R7.2, R8.1, U2.2 (GPIO1)
/GP2: J13.3, U2.4 (GPIO2)
/GP3: SW2.2, U2.5 (GPIO3)
/GP4: R6.2, U2.6 (GPIO4)
/GP5: J8.7, U2.7 (GPIO5)
/GP6: J8.6, U2.9 (GPIO6)
/GP7: J8.5, U2.10 (GPIO7)
/GP8: J5.3, J6.2, U2.11 (GPIO8)
/GP9: J5.4, J6.4, U2.12 (GPIO9)
/GP10: J8.4, J11.5 (CLK), U2.14 (GPIO10)
/GP11: J8.3, J11.3 (CMD), U2.15 (GPIO11)
/GP12: J11.7 (DAT0), U2.16 (GPIO12)
/GP13: J15.3, U2.17 (GPIO13)
/GP14: IC1.7 (BIN2_/_BENBL), IC1.9 (AIN2_/_AENBL), U2.19 (GPIO14)
/GP15: IC1.8 (BIN1_/_BPHASE), U2.20 (GPIO15)
/GP16: J14.1, U2.21 (GPIO16)
/GP17: IC1.10 (AIN1_/_APHASE), U2.22 (GPIO17)
/GP18: R5.2, U2.24 (GPIO18)
/GP19: U1.13 (BCK), U2.25 (GPIO19)
/GP20: U1.15 (LRCK), U2.26 (GPIO20)
/GP21: U1.14 (DIN), U2.27 (GPIO21)
/GP22: SW1.2, U2.29 (GPIO22)
/GP27: J11.2 (DAT3/CD), U2.32 (GPIO27_ADC1)
/GP28: J12.1, U2.34 (GPIO28_ADC2)
GND: C1.2, C2.2, C4.2, C5.2, C6.2, C7.2, C8.2, C9.2, C10.2, IC1.6 (GND_1), IC1.13 (GND_2), J1.A1_B12 (GND), J1.B1_A12 (GND), J1.S1 (SHIELD), J1.S2 (SHIELD), J1.S3 (SHIELD), J1.S4 (SHIELD), J2.S, J5.2, J6.3, J7.4, J8.2, J11.6 (VSS), J11.11 (SHIELD), J12.3, J13.1, J14.3, J15.1, Q1.2 (E), Q2.2 (E), R1.1, R4.1, R8.2, U1.3 (CPGND), U1.9 (AGND), U1.10 (DEMP), U1.11 (FLT), U1.12 (SCK), U1.16 (FMT), U1.19 (DGND), U2.3 (GND), U2.8 (GND), U2.13 (GND), U2.18 (GND), U2.23 (GND), U2.28 (GND), U2.38 (GND)
unnamed: C1.1, J2.T, R3.2
unnamed: C2.1, J2.R, R2.2
unnamed: IC1.2 (AOUT1), J9.1
unnamed: IC1.3 (AOUT2), J9.2
unnamed: IC1.4 (BOUT1), J10.1
unnamed: IC1.5 (BOUT2), J10.2
unnamed: J1.A5 (CC1), R1.2
unnamed: J1.B5 (CC2), R4.2
unnamed: J1.A7 (DN1), J1.B7 (DN2), U2.TP2 (USB_DM)
unnamed: J1.A6 (DP1), J1.B6 (DP2), U2.TP3 (USB_DP)
unnamed: J3.2, Q1.3 (C)
unnamed: J4.2, Q2.3 (C)
unnamed: J7.3, R7.1
unnamed: Q1.1 (B), R5.1
unnamed: Q2.1 (B), R6.1
unnamed: C3.2, U1.4 (CAPM)
unnamed: C3.1, U1.2 (CAPP)
unnamed: C8.1, U1.18 (LDOO)
unnamed: R3.1, U1.6 (OUTL)
unnamed: R2.1, U1.7 (OUTR)
unnamed: C4.1, U1.5 (VNEG)

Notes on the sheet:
Sensors
LEDs&Display
Serial In
Switches
Motors
Sound
Storage

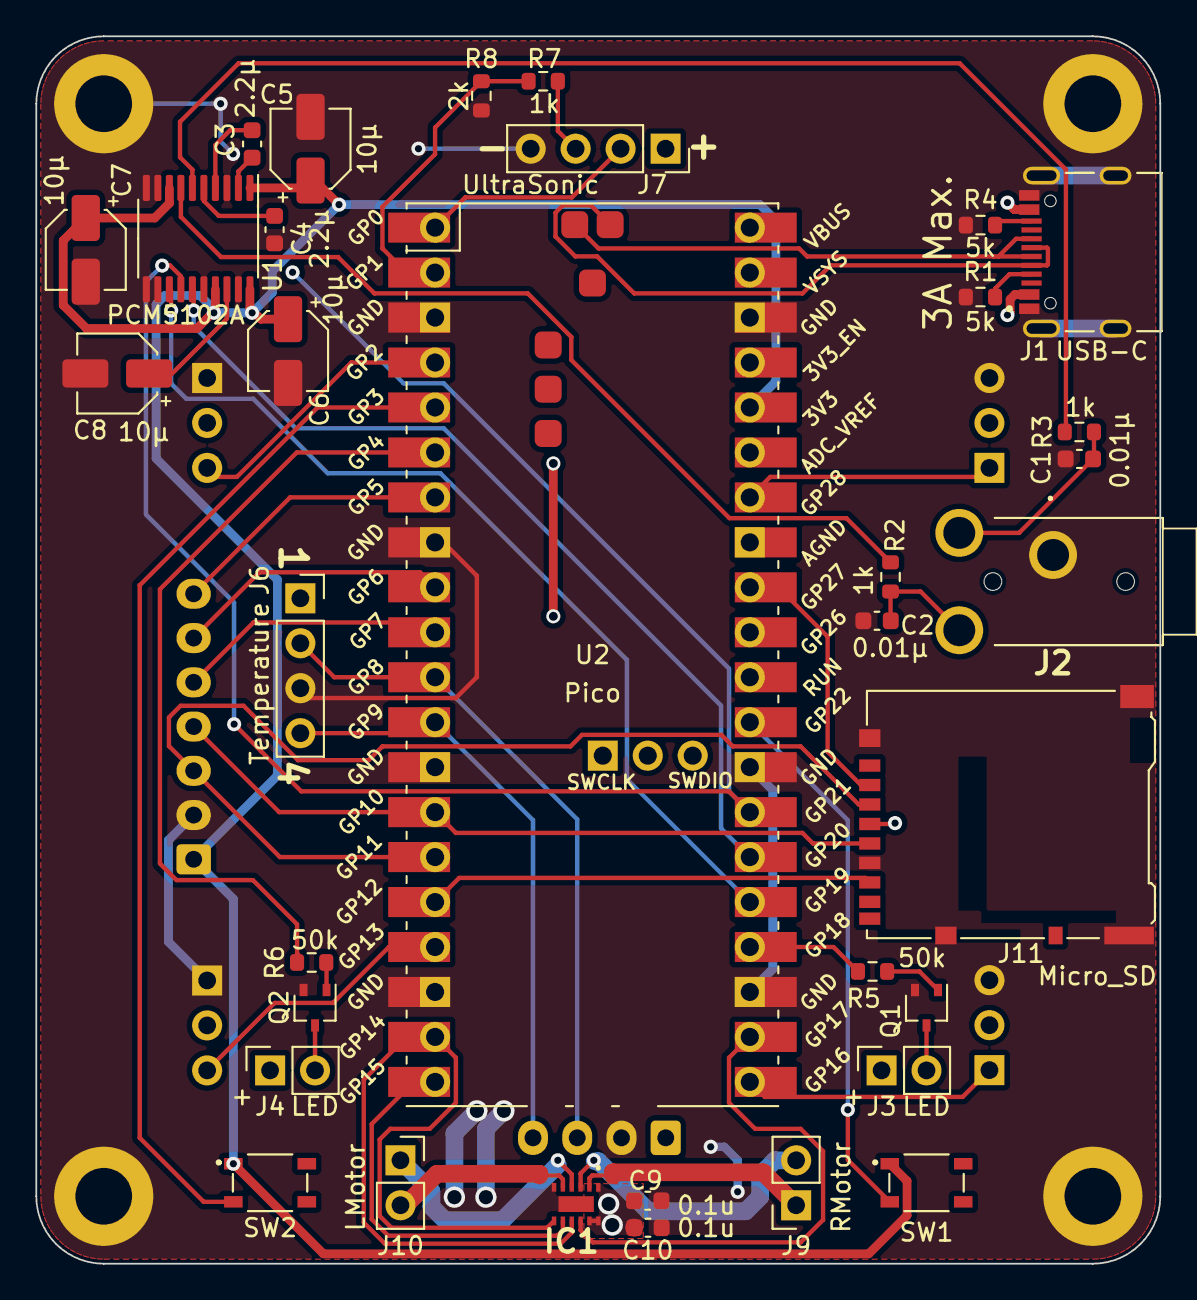
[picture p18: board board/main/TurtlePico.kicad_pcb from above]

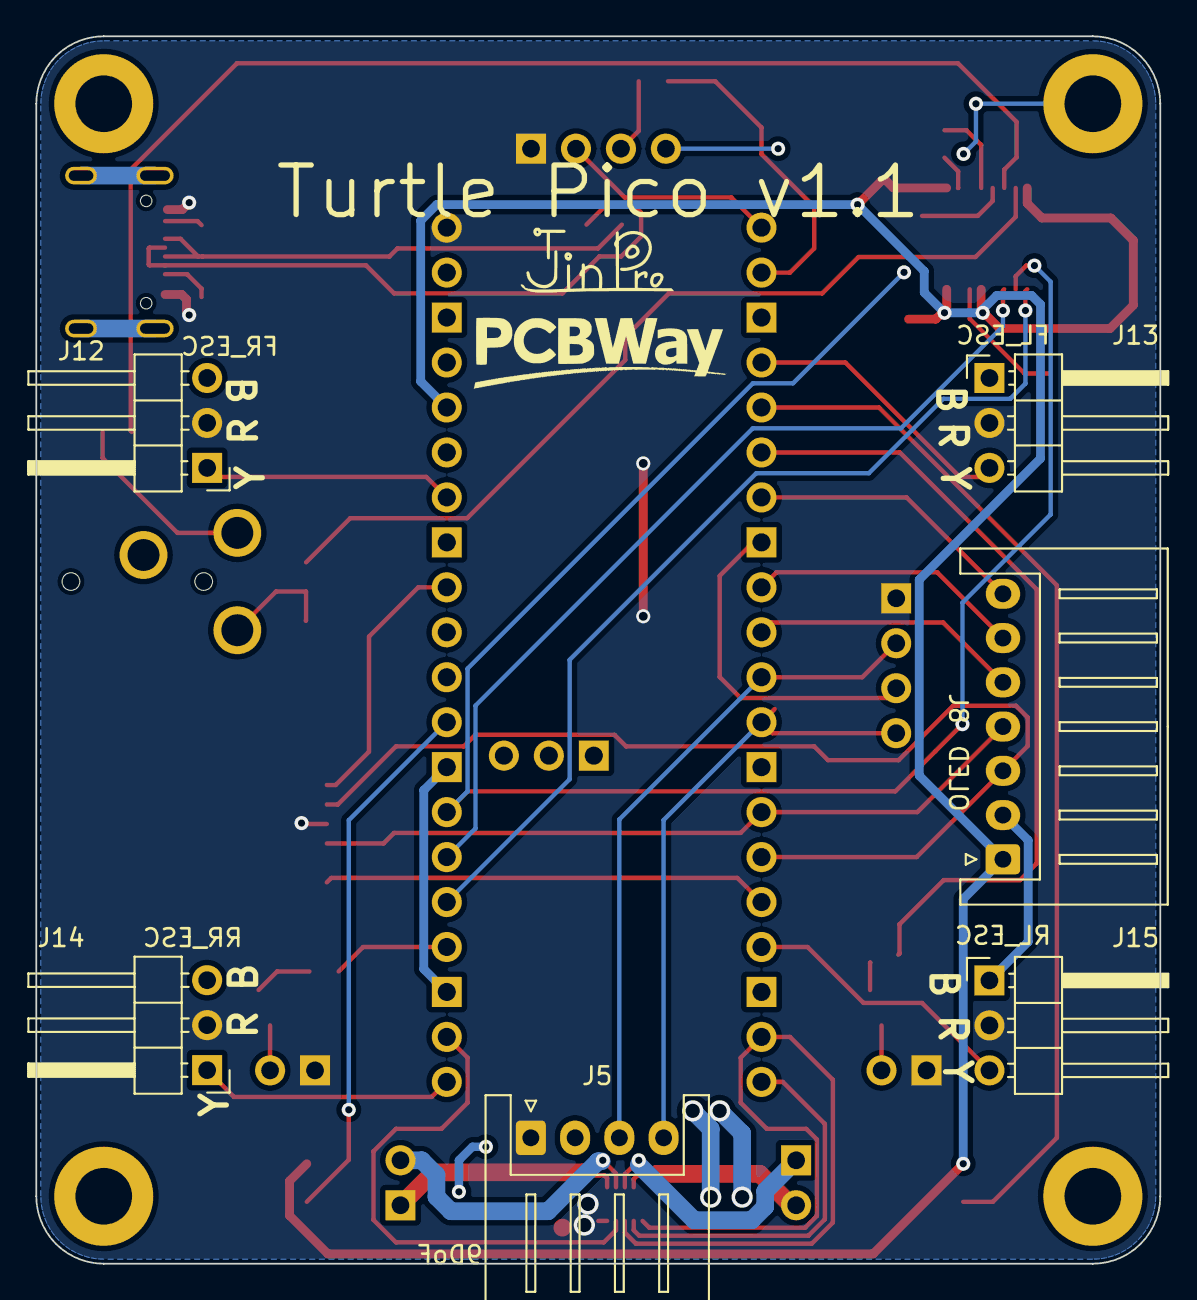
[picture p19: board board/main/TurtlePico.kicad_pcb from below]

Board: 2 copper layers, 63.5 x 69.3 mm, 40 parts (6 on the bottom side), 49 nets.

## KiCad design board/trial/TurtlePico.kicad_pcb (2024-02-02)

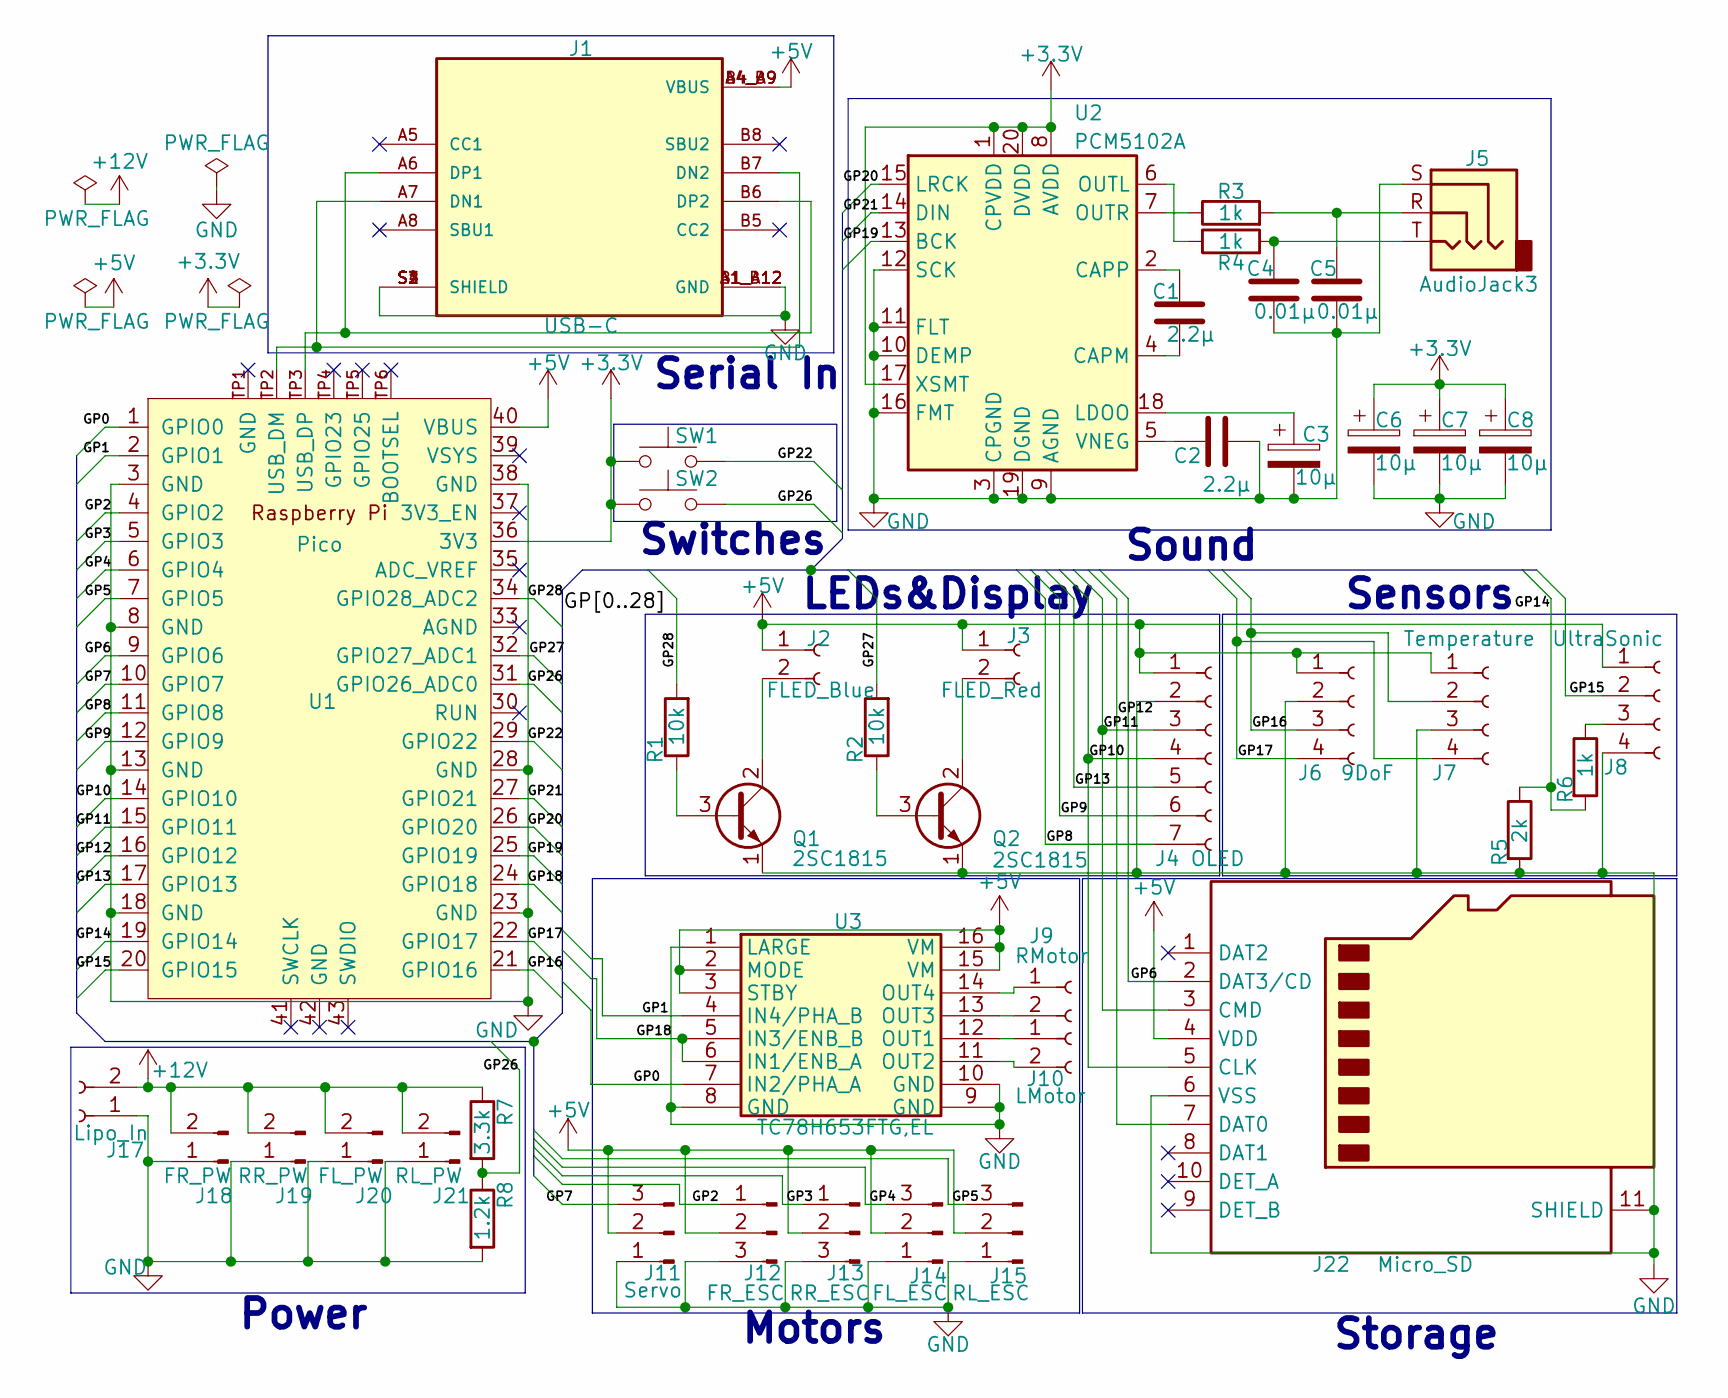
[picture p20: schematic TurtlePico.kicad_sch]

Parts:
C1, C2: 2.2µ; C_Disc_D5.1mm_W3.2mm_P5.00mm
C3, C6, C7, C8: 10µ; CP_Radial_D5.0mm_P2.00mm
C4, C5: 0.01µ; C_Disc_D4.3mm_W1.9mm_P5.00mm
J1: USB-C; NELTRON_5077CR-16SMC2-BK-TR; PARTREV B
J2: FLED_Blue; PinSocket_1x02_P2.54mm_Vertical
J3: FLED_Red; PinSocket_1x02_P2.54mm_Vertical
J4: OLED; JST_XH_S7B-XH-A_1x07_P2.50mm_Horizontal
J5: AudioJack3; Jack_3.5mm_Switronic_ST-005-G_horizontal
J6: 9DoF; JST_ZH_B4B-ZR_1x04_P1.50mm_Vertical
J7: Temperature; PinSocket_1x04_P2.54mm_Vertical
J8: UltraSonic; PinSocket_1x04_P2.54mm_Vertical
J9: RMotor; PinSocket_1x02_P2.54mm_Vertical
J10: LMotor; PinSocket_1x02_P2.54mm_Vertical
J11: Servo; PinHeader_1x03_P2.54mm_Horizontal
J12: FR_ESC; PinHeader_1x03_P2.54mm_Horizontal
J13: RR_ESC; PinHeader_1x03_P2.54mm_Horizontal
J14: FL_ESC; PinHeader_1x03_P2.54mm_Horizontal
J15: RL_ESC; PinHeader_1x03_P2.54mm_Horizontal
J17: Lipo_In; AMASS_XT60PW-M_1x02_P7.20mm_Horizontal
J18: FR_PW; AMASS_XT60PW-F_1x02_P7.20mm_Horizontal
J19: RR_PW; AMASS_XT60PW-F_1x02_P7.20mm_Horizontal
J20: FL_PW; AMASS_XT60PW-F_1x02_P7.20mm_Horizontal
J21: RL_PW; AMASS_XT60PW-F_1x02_P7.20mm_Horizontal
J22: Micro_SD; microSD_HC_Hirose_DM3AT-SF-PEJM5
Q1, Q2: 2SC1815; TO-92_Inline
R1, R2: 10k; R_Axial_DIN0207_L6.3mm_D2.5mm_P10.16mm_Horizontal
R3, R4, R6: 1k; R_Axial_DIN0207_L6.3mm_D2.5mm_P10.16mm_Horizontal
R5: 2k; R_Axial_DIN0207_L6.3mm_D2.5mm_P10.16mm_Horizontal
R7: 3.3k; R_Axial_DIN0207_L6.3mm_D2.5mm_P10.16mm_Horizontal
R8: 1.2k; R_Axial_DIN0207_L6.3mm_D2.5mm_P10.16mm_Horizontal
SW1, SW2: SW_Push; SW_SKRPACE010
U1: Pico; RPi_Pico_SMD_TH
U2: PCM5102A; PCM5102A_DIP
U3: TC78H653FTG,EL; DIP-16_W7.62mm; Mouser Part Number 757-TC78H653FTGEL

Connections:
+3.3V: C6.1, C7.1, C8.1, SW1.1, SW2.1, U1.36 (3V3), U2.1 (CPVDD), U2.8 (AVDD), U2.17 (XSMT), U2.20 (DVDD)
+5V: J1.A4_B9 (VBUS), J1.B4_A9 (VBUS), J2.1, J3.1, J4.1, J6.1, J7.1, J8.1, J11.2, J12.2, J13.2, J14.2, J15.2, J22.4 (VDD), U1.40 (VBUS), U3.2 (MODE), U3.3 (STBY), U3.15 (VM), U3.16 (VM)
+12V: J17.2, J18.2, J19.2, J20.2, J21.2, R7.1
/GP0: U1.1 (GPIO0), U3.7 (IN2/PHA_A)
/GP1: U1.2 (GPIO1), U3.4 (IN4/PHA_B)
/GP2: J12.1, U1.4 (GPIO2)
/GP3: J13.1, U1.5 (GPIO3)
/GP4: J14.3, U1.6 (GPIO4)
/GP5: J15.3, U1.7 (GPIO5)
/GP6: J22.2 (DAT3/CD), U1.9 (GPIO6)
/GP7: J11.3, U1.10 (GPIO7)
/GP8: J4.7, U1.11 (GPIO8)
/GP9: J4.6, U1.12 (GPIO9)
/GP10: J4.4, J22.5 (CLK), U1.14 (GPIO10)
/GP11: J4.3, J22.3 (CMD), U1.15 (GPIO11)
/GP12: J22.7 (DAT0), U1.16 (GPIO12)
/GP13: J4.5, U1.17 (GPIO13)
/GP14: R5.1, R6.2, U1.19 (GPIO14)
/GP15: J8.2, U1.20 (GPIO15)
/GP16: J6.3, J7.2, U1.21 (GPIO16)
/GP17: J6.4, J7.4, U1.22 (GPIO17)
/GP18: U1.24 (GPIO18), U3.5 (IN3/ENB_B), U3.6 (IN1/ENB_A)
/GP19: U1.25 (GPIO19), U2.13 (BCK)
/GP20: U1.26 (GPIO20), U2.15 (LRCK)
/GP21: U1.27 (GPIO21), U2.14 (DIN)
/GP22: SW1.2, U1.29 (GPIO22)
/GP26: R7.2, R8.1, SW2.2, U1.31 (GPIO26_ADC0)
/GP28: R1.2, U1.34 (GPIO28_ADC2)
unnamed: C4.1, J5.T, R4.2
unnamed: C5.1, J5.R, R3.2
unnamed: J1.A7 (DN1), J1.B7 (DN2), U1.TP2 (USB_DM)
unnamed: J1.A6 (DP1), J1.B6 (DP2), U1.TP3 (USB_DP)
unnamed: J2.2, Q1.2 (C)
unnamed: J3.2, Q2.2 (C)
unnamed: J8.3, R6.1
unnamed: J9.1, U3.14 (OUT4)
unnamed: J9.2, U3.13 (OUT3)
unnamed: J10.1, U3.12 (OUT1)
unnamed: J10.2, U3.11 (OUT2)
unnamed: Q1.3 (B), R1.1
unnamed: Q2.3 (B), R2.1
unnamed: C1.2, U2.4 (CAPM)
unnamed: C1.1, U2.2 (CAPP)
unnamed: C3.1, U2.18 (LDOO)
unnamed: R4.1, U2.6 (OUTL)
unnamed: R3.1, U2.7 (OUTR)
unnamed: C2.1, U2.5 (VNEG)

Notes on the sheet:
Sensors
LEDs&Display
Serial In
Switches
Motors
Sound
Storage
Power

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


Board: 4 copper layers, 63.5 x 99.3 mm, 44 parts (13 on the bottom side), 49 nets.

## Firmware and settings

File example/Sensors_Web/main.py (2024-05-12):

import _thread
import machine
from machine import Pin, I2C, SPI
import time
import ustruct
import math
from lib.ssd1306 import SSD1306_SPI
from lib.img_lib import img_lib
import framebuf
import network
import socket
from lib.TurtlePico import TurtlePico

#i2c設定
i2c = I2C(TurtlePico.I2C_ID, scl=Pin(TurtlePico.I2C_SCL), sda=Pin(TurtlePico.I2C_SDA), freq=100000)
#spi設定
spi = SPI(TurtlePico.SPI_ID, baudrate = 100000, sck = Pin(TurtlePico.SPI_SCK), mosi = Pin(TurtlePico.SPI_MOSI))

#アドレスを設定
addr_ag = 0x6a
addr_m = 0x1c
addr_temp = 0x38
#自宅Wi-FiのSSIDとパスワードを入力
ssid = 'SSID'
password = 'PASS'

#ピンを設定
trig = Pin(TurtlePico.TRIG_TX, Pin.OUT)
echo = Pin(TurtlePico.ECHO_RX, Pin.IN)
cs = Pin(TurtlePico.OLED_CS, Pin.OUT)
dc = Pin(TurtlePico.OLED_DC, Pin.OUT)
rst = Pin(TurtlePico.OLED_RST, Pin.OUT)

#OLEDを初期化
display = SSD1306_SPI(128, 64, spi, dc, rst, cs)
fb = framebuf.FrameBuffer(img_lib.techring, 74, 64, framebuf.MONO_HLSB)

#加速度・ジャイロセンサのレジスタ
CTRL_REG1_G = 0x10
CTRL_REG2_G = 0x11
CTRL_REG3_G = 0x12
ORIENT_CFG_G = 0x13
CTRL_REG4 = 0x1E
CTRL_REG5_XL = 0x1F
CTRL_REG6_XL = 0x20
CTRL_REG7_XL = 0x21

#センサの設定
i2c.writeto_mem(addr_ag, CTRL_REG1_G, b'\x60')  #0110 0000
i2c.writeto_mem(addr_ag, CTRL_REG2_G, b'\x00')  #0000 0000
i2c.writeto_mem(addr_ag, CTRL_REG3_G, b'\x41')  #0100 0001
i2c.writeto_mem(addr_ag, ORIENT_CFG_G, b'\x40') #0100 0000
i2c.writeto_mem(addr_ag, CTRL_REG4, b'\x3a')    #0011 1010
i2c.writeto_mem(addr_ag, CTRL_REG5_XL, b'\x38') #0011 1000
i2c.writeto_mem(addr_ag, CTRL_REG6_XL, b'\x3c') #0011 1100
i2c.writeto_mem(addr_ag, CTRL_REG7_XL, b'\x00') #0000 0000

#磁気センサのレジスタ
CTRL_REG1_M = 0x20
CTRL_REG2_M = 0x21
CTRL_REG3_M = 0x22
CTRL_REG4_M = 0x23
CTRL_REG5_M = 0x24

#センサの設定
i2c.writeto_mem(addr_m, CTRL_REG1_M, b'\x14')  #0001 0100
i2c.writeto_mem(addr_m, CTRL_REG2_M, b'\x40')  #0100 0000
i2c.writeto_mem(addr_m, CTRL_REG3_M, b'\x00')  #0000 0000
i2c.writeto_mem(addr_m, CTRL_REG4_M, b'\x0c')  #0000 1100
i2c.writeto_mem(addr_m, CTRL_REG5_M, b'\x00')  #0000 0000

#加速度、ジャイロ、磁気の変数
AccX, AccY, AccZ = 0, 0, 0
GyrX, GyrY, GyrZ = 0, 0, 0
MagX, MagY, MagZ = 0, 0, 0
text_hum, text_temp, text_distance = "", "", ""

#Wi-Fiに接続
wlan = network.WLAN(network.STA_IF)
wlan.active(True)
wlan.connect(ssid, password)

#HTMLを定義
html = """<!DOCTYPE html><html>
<head>
    <meta name="viewport" content="width=device-width, initial-scale=1">
    <link rel="icon" href="data:,">
    <style> html { font-family: Helvetica; display: inline-block; margin: 0px auto; text-align: center;}
        .buttonGreen { background-color: #4CAF50; border: 2px solid #000000;; color: white; padding: 15px 32px; text-align: center; text-decoration: none; display: inline-block; font-size: 16px; margin: 4px 2px; cursor: pointer; }
        .buttonRed { background-color: #D11D53; border: 2px solid #000000;; color: white; padding: 15px 32px; text-align: center; text-decoration: none; display: inline-block; font-size: 16px; margin: 4px 2px; cursor: pointer; }
        .buttonBlue { background-color: #191970; border: 2px solid #000000;; color: white; padding: 15px 32px; text-align: center; text-decoration: none; display: inline-block; font-size: 16px; margin: 4px 2px; cursor: pointer; }
        .contents { overflow: hidden; padding: auto; width: 100%%; margin: 0 auto; }
        .item { width: 33%%; float: left; text-align: center; }
    </style>
</head>
<body>
    <center>
        <h1>Get Sensors Value</h1>
    </center><br><br>
    <div class="contents">
        <h2 style="color: red;">Acceleration</h2>
        <div class="item">
            <h3>Acceleration_X</h3>
            <p>%s</p>
        </div>
        <div class="item">
            <h3>Acceleration_Y</h3>
            <p>%s</p>
        </div>
        <div class="item">
            <h3>Acceleration_Z</h3>
            <p>%s</p>
        </div>
    </div>
    <div class="contents">
        <h2 style="color: red;">Gyro</h2>
        <div class="item">
            <h3>Gyro_Z</h3>
            <p>%s</p>
        </div>
        <div class="item">
            <h3>Gyro_Y</h3>
            <p>%s</p>
        </div>
        <div class="item">
            <h3>Gyro_Z</h3>
            <p>%s</p>
        </div>
    </div>
    <div class="contents">
        <h2 style="color: red;">Magnetic</h2>
        <div class="item">
            <h3>Magnetic_X</h3>
            <p>%s</p>
        </div>
        <div class="item">
            <h3>Magnetic_Y</h3>
            <p>%s</p>
        </div>
        <div class="item">
            <h3>Magnetic_Z</h3>
            <p>%s</p>
        </div>
    </div>
    <center>
        <h2 style="color: red;">Humidity</h2>
        <p>%s</p><br><br>
        <h2 style="color: red;">Temperature</h2>
        <p>%s</p><br><br>
        <h2 style="color: red;">Distance</h2>
        <p>%s</p><br><br>
    </center>
</body>
</html>"""

#起動アニメーションの表示
display.fill(0)
display.blit(fb, int((128-74) / 2), 0)
display.show()
#time.sleep(3)
for i in range(1, 64):
    display.fill(0)
    display.blit(fb, int((128-74) / 2), -i)
    display.show()
    time.sleep(0.01)

#wifiの接続を待機
max_wait = 10
while max_wait > 0:
    if wlan.status() < 0 or wlan.status() >= 3:
        break
    max_wait -= 1
    print('waiting for connection...')
    display.fill(0)
    display.text('waiting for connection...', 0, 0, 1)
    display.show()
    time.sleep(1)

#接続できなかった場合はエラーを表示
if wlan.status() != 3:
    raise RuntimeError('network connection failed')
#接続できた場合はIPアドレスを表示
else:
    print('Connected')
    print(wlan.ifconfig()[0])

#ソケットを作成
addr = socket.getaddrinfo('0.0.0.0', 80)[0][-1]
s = socket.socket()
s.bind(addr)
s.listen(1)
print('listening on', addr)

def task():
    global AccX, AccY, AccZ, GyrX, GyrY, GyrZ, MagX, MagY, MagZ, text_hum, text_temp, text_distance

    while True:#ディスプレイ初期化
        display.fill(0)
        display.text('Connected', int(128 / 2 - len('Connected') * 4), 0, 1)
        display.text(wlan.ifconfig()[0], int(128 / 2 - len(wlan.ifconfig()[0]) * 4), 8, 1)

        print("=======================================================")
        #アドレス0x27のstatusレジスタの下から1ビット目が加速度のデータ更新状態
        status = i2c.readfrom_mem(addr_ag, 0x27, 1)
        if status and 0x01 != 0x00:
            #加速度センサのデータの読み込み
            data = b''
            for i in range(0x28, 0x2e):
                data += i2c.readfrom_mem(addr_ag, i, 1)
            AccX = ustruct.unpack("<h", data[0:2])[0]
            AccY = ustruct.unpack("<h", data[2:4])[0]
            AccZ = ustruct.unpack("<h", data[4:6])[0]
            AccX = AccX * 0.000244
            AccY = AccY * 0.000244
            AccZ = AccZ * 0.000244
            print("AccX:" + '{:.2f}'.format(AccX) + " AccY:" + '{:.2f}'.format(AccY) + " AccZ:" + '{:.2f}'.format(AccZ))
            phi = math.atan(-AccY/AccX)
            thete = math.atan(AccX/math.sqrt(AccY*AccY+AccZ*AccZ))
            print("phi:" + '{:.2f}'.format(phi) + " thete:" + '{:.2f}'.format(thete))
        
        #アドレス0x27のstatusレジスタの下から2ビット目がジャイロのデータ更新状態
        if status and 0x02 != 0x00:
            data = b''
            for i in range(0x18, 0x1e):
                data += i2c.readfrom_mem(addr_ag, i, 1)
            GyrX = ustruct.unpack("<h", data[0:2])[0]
            GyrY = ustruct.unpack("<h", data[2:4])[0]
            GyrZ = ustruct.unpack("<h", data[4:6])[0]
            GyrX = GyrX * 0.00875
            GyrY = GyrY * 0.00875
            GyrZ = GyrZ * 0.00875
            print("GyrX:" + '{:.2f}'.format(GyrX) + " GyrY:" + '{:.2f}'.format(GyrY) + " GyrZ:" + '{:.2f}'.format(GyrZ))
        
        status = i2c.readfrom_mem(addr_m, 0x27, 1)
        #アドレス0x27のstatusレジスタの下から4ビット目が磁気のデータ更新状態
        if status and 0x08 != 0x00:
            data = i2c.readfrom_mem(addr_m, 0x28, 6)
            MagX = ustruct.unpack("<h", data[0:2])[0]
            MagY = ustruct.unpack("<h", data[2:4])[0]
            MagZ = ustruct.unpack("<h", data[4:6])[0]
            MagX = MagX * 0.00043
            MagY = MagY * 0.00043
            MagZ = MagZ * 0.00043
            print("MagX:" + '{:.2f}'.format(MagX) + " MagY:" + '{:.2f}'.format(MagY) + " MagZ:" + '{:.2f}'.format(MagZ))

        #測定コマンドを送信
        i2c.writeto(addr_temp, b'\xAC\x33\x00')

        #測定結果を読み込む
        data = i2c.readfrom(addr_temp, 6)

        #温湿度データを取得
        hum = data[1] << 12 | data[2] << 4 | (data[3] & 0xF0) >> 4
        temp = ((data[3] & 0x0F) << 16) | data[4] << 8 | data[5]

        hum = hum / 2**20 * 100
        temp = temp / 2**20 * 200 - 50
        text_hum = "hum : " + '{:.2f}'.format(hum) + "%"
        text_temp = "temp : " + '{:.2f}'.format(temp) + "C"

        print("=======================================================")

        #ディスプレイとログに温湿度を表示
        print(text_hum)
        print(text_temp)
        display.text(text_hum, int(128 / 2 - len(text_hum) * 4), 24, 1)
        display.text(text_temp, int(128 / 2 - len(text_temp) * 4), 32, 1)

        #トリガ波形を出力
        trig.low()
        time.sleep_us(2)
        trig.high()
        time.sleep_us(10)
        trig.low()

        #エコーの立ち下がりから立ち上がりまでの時間を計測
        signaloff, signalon = 0, 0
        while echo.value() == 0:
            signaloff = time.ticks_us()
        while echo.value() == 1:
            signalon = time.ticks_us()
        
        #エコーの時間差から距離を計算
        timepassed = signalon - signaloff
        distance = (timepassed * 0.0343) / 2
        text_distance = "dist : " + '{:.2f}'.format(distance) + "cm"

        print(text_distance)
        display.text(text_distance, int(128 / 2 - len(text_distance) * 4), 40, 1)

        display.show()
        time.sleep(1)

_thread.start_new_thread(task,())

while True:
    cl, addr = s.accept()
    try:
        #クライアントからのリクエストを解析
        print('client connected from', addr)
        
        #HTMLをクライアントに送信
        response = html % ('{:.2f}'.format(AccX) + "g", '{:.2f}'.format(AccY) + "g", '{:.2f}'.format(AccZ) + "g",
                        '{:.2f}'.format(GyrX) + "dps", '{:.2f}'.format(GyrY) + "dps", '{:.2f}'.format(GyrZ) + "dps",
                        '{:.2f}'.format(MagX) + "gauss", '{:.2f}'.format(MagY) + "gauss", '{:.2f}'.format(MagZ) + "gauss",
                        text_hum, text_temp, text_distance)
        cl.send('HTTP/1.0 200 OK\r\nContent-type: text/html\r\n\r\n')
        cl.send(response)
        cl.close()
        
    except Exception as e:
        cl.close()
        print(e)

    except KeyboardInterrupt:
        print("KeyboardInterrupt")
        machine.reset()

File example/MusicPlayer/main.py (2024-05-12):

from machine import PWM, Pin, SPI, reset
from wavplayer import WavPlayer
import os
from lib.sdcard import SDCard
from lib.ssd1306 import SSD1306_SPI
from lib.img_lib import img_lib
import framebuf
import time
from lib.TurtlePico import TurtlePico

#Pin設定
orange = PWM(Pin(TurtlePico.LED_R, Pin.OUT))
green = PWM(Pin(TurtlePico.LED_L, Pin.OUT))
playSW = Pin(TurtlePico.SW_R, Pin.IN, Pin.PULL_DOWN)
stopSW = Pin(TurtlePico.SW_L, Pin.IN, Pin.PULL_DOWN)
#oled
oled_cs = Pin(TurtlePico.OLED_CS)
dc = Pin(TurtlePico.OLED_DC)
rst = Pin(TurtlePico.OLED_RST)
#sd
sd_cs = Pin(TurtlePico.SD_CS)
#i2s
sck_pin = Pin(TurtlePico.I2S_BCLK)   # シリアルクロック出力
ws_pin = Pin(TurtlePico.I2S_LRCLK)    # ワードクロック出力
sd_pin = Pin(TurtlePico.I2S_SDATA)    # シリアルデータ出力
#ultrasonic
trig = Pin(TurtlePico.TRIG_TX, Pin.OUT)
echo = Pin(TurtlePico.ECHO_RX, Pin.IN)

orange.freq(1000)
green.freq(1000)

spi = SPI( TurtlePico.SPI_ID,
           baudrate = 100000,
           sck  = Pin(TurtlePico.SPI_SCK),
           mosi = Pin(TurtlePico.SPI_MOSI),
           miso = Pin(TurtlePico.SPI_MISO))

sd = SDCard(spi, sd_cs)
display = SSD1306_SPI(128, 64, spi, dc, rst, oled_cs)
fb = framebuf.FrameBuffer(img_lib.techring, 74, 64, framebuf.MONO_HLSB)

def main():

    os.mount(sd, '/sd')
    os.chdir('sd')
    list = os.listdir("/sd")

    #jin_imgを表示
    display.fill(0)
    display.blit(fb, int((128-74) / 2), 0)
    display.show()
    time.sleep(3)

    try: 
        for i in range(1, 64):
            display.fill(0)
            display.blit(fb, int((128-74) / 2), -i)
            display.show()
            time.sleep(0.01)
        
        for i in range(0, len(list)):
            green.duty_u16(65535)
            orange.duty_u16(0)

            if(list[i].find(".wav") == -1):
                continue
            
            wp = WavPlayer(
                id=TurtlePico.I2S_ID,
                sck_pin=sck_pin,
                ws_pin=ws_pin,
                sd_pin=sd_pin,
                ibuf=40000,
            )
            wp.play(list[i], loop=False)
            display.fill(0)
            display.text(list[i], 0, 0)
            display.show()

            j = 0
            while wp.isplaying():
                distance = messure_distance()
                print(distance,"cm")
                if(j > 128):
                    j = 0
                else:
                    j += 1

                display.fill(0)
                display.text(list[i], -j, 0)
                display.show()

                if distance < 5:
                    print("skip")
                    wp.stop()
                    green.duty_u16(0)
                    orange.duty_u16(65535)
                    time.sleep(0.5)
                    break
                if stopSW.value() == 1:
                    #print("pause")
                    #wp.pause()
                    wp.increase_volume()
                    #green.duty_u16(0)
                    #orange.duty_u16(65535)
                if playSW.value() == 1:
                    #print("resume")
                    #wp.resume()
                    wp.decrease_volume()
                    #green.duty_u16(65535)
                    #orange.duty_u16(0)
                time.sleep(0.15)
                pass
            time.sleep(0.5)

    except KeyboardInterrupt:
        print("KeyboardInterrupt")
        reset()

def messure_distance():
    trig.low()
    time.sleep_us(2)
    trig.high()
    time.sleep_us(10)
    trig.low()
    signaloff, signalon = 0, 0
    while echo.value() == 0:
        signaloff = time.ticks_us()
    while echo.value() == 1:
        signalon = time.ticks_us()
    timepassed = signalon - signaloff
    dis = (timepassed * 0.0343) / 2
    return dis

if __name__ == "__main__":
    main()
    display.fill(0)
    display.text("end", 0, 0)
    display.show()
    reset()

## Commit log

2023-07-29 add ultrasonic sensor
2023-07-29 add Temperature sensor
2023-07-29 add sensors_web & oled code
2023-08-01 add sch and library
    [PicoDriver.kicad_pcb, PicoDriver.kicad_sch]
2023-08-01 edit pico library
2023-08-02 add Servo and DC Motor
    [PicoDriver.kicad_sch]
2023-08-03 fix sch
    [PicoDriver.kicad_sch]
2023-08-03 add BLDC and fix sch
    [PicoDriver.kicad_sch]
2023-08-05 add Turtle Pico that is Driver
    [PicoDriver.kicad_pcb, PicoDriver.kicad_sch, TurtlePico.kicad_pcb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]
2023-08-07 add step and change 4layers
    [TurtlePico-B_Cu.gbr, TurtlePico-B_Mask.gbr, TurtlePico-B_Paste.gbr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]
2023-08-15 add text
    [TurtlePico.kicad_pcb]
2023-08-23 edit connection
    [TurtlePico.kicad_pcb, TurtlePico.kicad_sch]
2023-10-19 add MusicPlayer
    [TurtlePico.step]
2024-02-02 add version folder
    [TurtlePico-B_Cu.gbr, TurtlePico-B_Mask.gbr, TurtlePico-B_Paste.gbr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]
2024-02-02 change version
    [TurtlePico.kicad_pcb]
2024-02-03 Turtle Pico Update v1.0
    [TurtlePico-B_Cu.gbr, TurtlePico-B_Mask.gbr, TurtlePico-B_Paste.gbr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]
2024-02-03 add step file v1.0
    [TurtlePico.step]
2024-02-03 change BJT and some design
    [TurtlePico-B_Cu.gbr, TurtlePico-B_Mask.gbr, TurtlePico-B_Paste.gbr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]
2024-04-25 add ledtape
2024-05-06 update v1.1 fix usb
    [TurtlePico-B_Cu.gbr, TurtlePico-B_Mask.gbr, TurtlePico-B_Paste.gbr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]
2024-05-07 update v.1 change uart and ultrasonic pin
    [TurtlePico-B_Cu.gbr, TurtlePico-B_Mask.gbr, TurtlePico-B_Paste.gbr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]
2024-05-09 add TurtlePico.py that is Pin Define
2024-05-12 edit TurtlePico.py
    [TurtlePico-B_Cu.gbr, TurtlePico-B_Mask.gbr, TurtlePico-B_Paste.gbr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]
2024-07-15 add case
    [LowerCase.step, UpperCase.step]
2024-07-17 add bom and change some directory
    [LowerCase.step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]
2024-07-17 remove cache
    [TurtlePico-B_Cu.gbr, TurtlePico-B_Mask.gbr, TurtlePico-B_Paste.gbr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]
2024-07-17 change directory structure
    [LowerCase.step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]
2024-07-17 update uppercase
    [UpperCase.step]
2024-07-17 Turtle Pico Overview
2024-07-30 add clock function(only digital) in TurtlePico-Dashboard
    [TurtlePico-B_Cu.gbr, TurtlePico-B_Mask.gbr, TurtlePico-B_Paste.gbr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]
2024-09-10 add mini model
    [TurtlePico-Minimal.kicad_pcb, TurtlePico-Minimal.kicad_sch]
2024-09-10 update minimal model
    [TurtlePico-Minimal.kicad_sch, untitled.kicad_sch]
2024-09-10 update schematics
    [TurtlePico-Minimal.kicad_sch, untitled.kicad_sch]
2024-09-16 update PCB and edit schematic
    [Connector.kicad_sch, LED_Switch.kicad_sch, Motor.kicad_sch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]
2024-11-08 add Weather to Dashboard
    [Audio.kicad_sch, LED_Switch.kicad_sch, Motor.kicad_sch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]
